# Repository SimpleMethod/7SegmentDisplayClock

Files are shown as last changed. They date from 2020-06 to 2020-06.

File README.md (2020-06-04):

# 🕰️ 7 Segment display clock - simple segment clock based on the STM32 MCU using GPS time as a reference source.

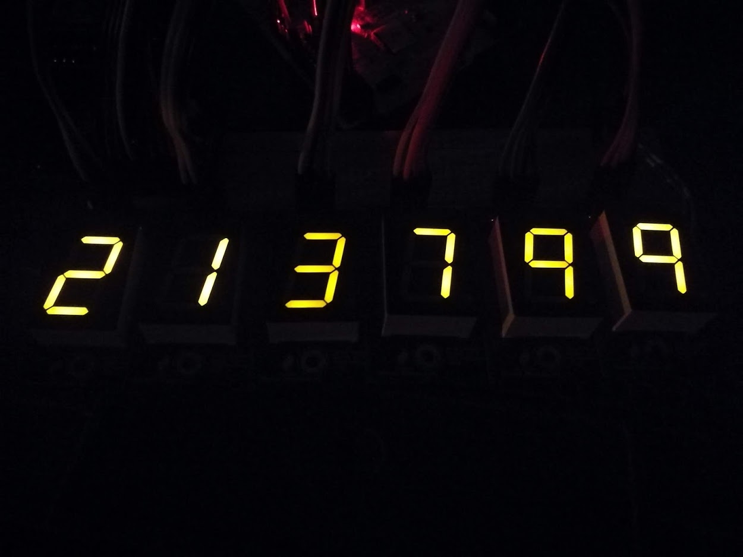
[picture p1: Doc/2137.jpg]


# 🧗‍♂️Main milestones

1. Retrieving date and time from GPS and saving it to RTC.
2. Creating a PCB to display numbers using a 7 segment display.

# 🚀 Features
 1. Retrieving date and time from GPS.
2.  Information users by buzzer signals. 
3.  Setting alarms.
4.  Display date and time on 7 segment display.

# 🗺️ Technologies used in project 
 - Based on microcontroller STM32
- Used CD4511BE as BCD code decoder.
- Used GPS Ublox NEO-M8 as GPS signal receiver.
- Used DS3212 as RTC clock.
-  Development necessary libraries based on technical documentation,

# 🧪 Visualization PCB shield
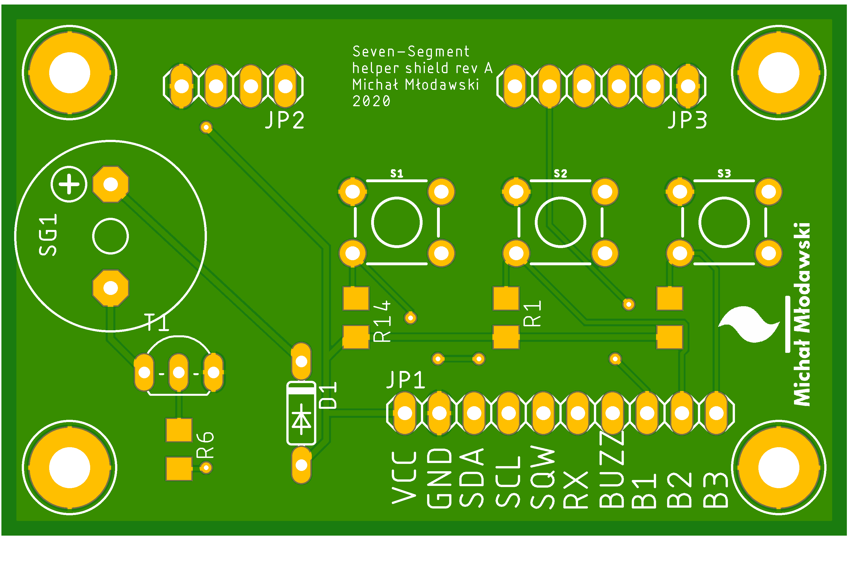
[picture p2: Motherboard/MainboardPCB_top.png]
MainShield


# 🧪 Visualization PCB display top side
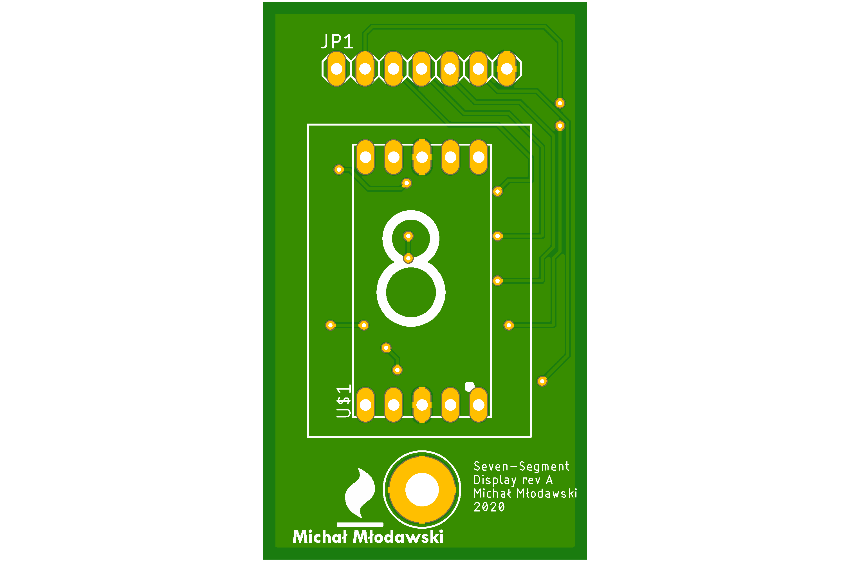
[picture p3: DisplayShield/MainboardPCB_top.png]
dispaly top


# 🧪 Visualization PCB display bottom side

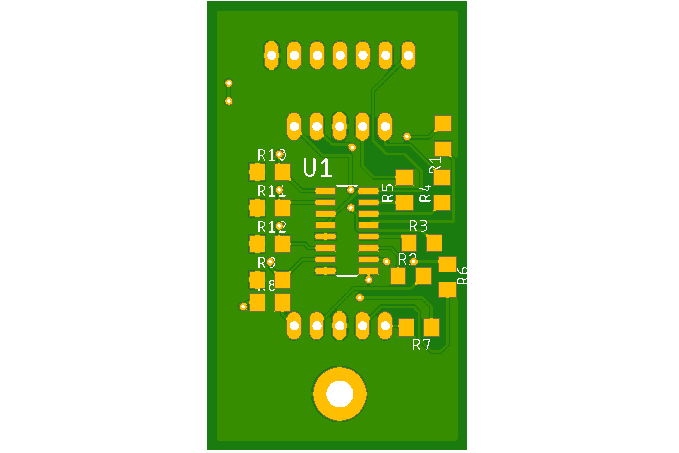
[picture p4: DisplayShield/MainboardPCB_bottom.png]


# ⚡ Circuit diagrams

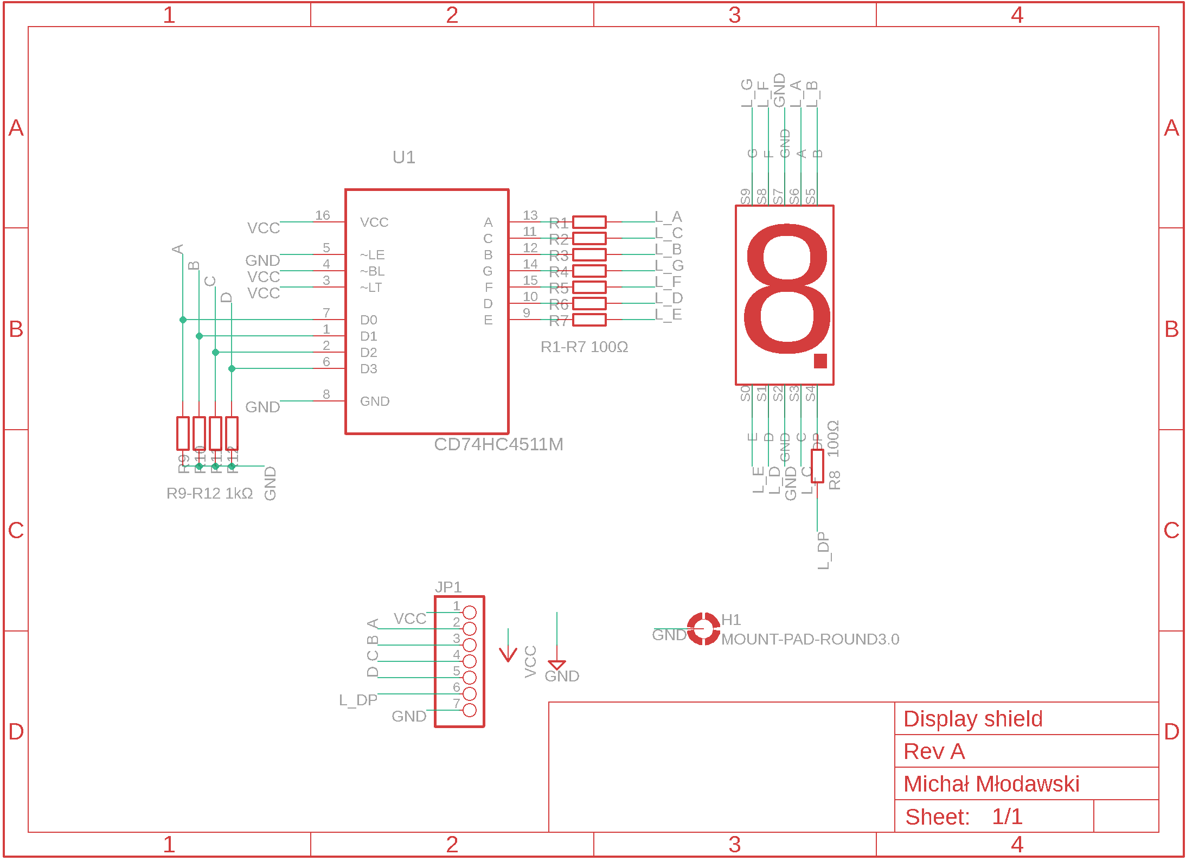
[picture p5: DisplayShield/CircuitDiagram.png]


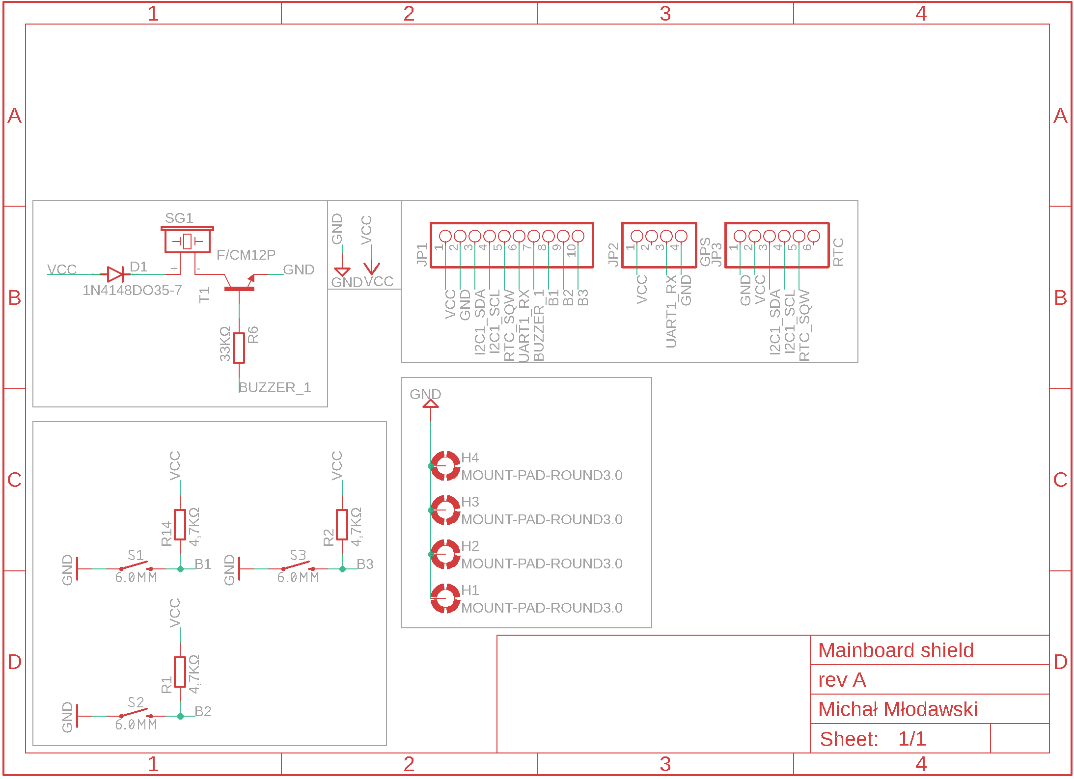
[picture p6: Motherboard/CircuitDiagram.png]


## 🎥  Video of the presentation:

[https://youtu.be/eESlLnk6x-c](https://youtu.be/eESlLnk6x-c)

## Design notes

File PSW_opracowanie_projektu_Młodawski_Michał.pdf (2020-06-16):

For educational purposes only

# Politechnika Świętokrzyska w Kielcach

# Wydział Elektroniki, Automatyki i Informatyki

## Projekt: Programowanie Systemów Wbudowanych

### Grupa:

### 1ID21A

## Temat:

## Zegar z wyświetlaczem siedmiosegmentowym

### Skład grupy:

### Michał Młodawski

### Rok studiów:

4

## Zegar z wyświetlaczem siedmiosegmentowym – Pobieranie czasu z sytemu GPS

## Opracowanie projektu

## Czerwiec 2020

Wersja dokumentu 16062020-001PL

# 1. Opis projektu

Projekt miał na celu stworzenie zegara opartego na wyświetlaczu siedmiosegmentowym umożliwiającym pobieranie daty i godziny przy użyciu sygnału GPS (ang. Global Positioning System), następnie zapisaniu daty i godziny do zegara czasu rzeczywistego RTC DS3231 i wyświetlenie ich następnie na wyświetlaczach siedmiosegmentowych.

# 2. Wykorzystane technologie

Jako główny mikrokontroler został wykorzystany mikrokontroler STM32F411RETx do pobierania czasu z systemu pozycjonowania GPS został użyty układ ublox neo-6m, natomiast do przechowywania czasu układ DS3231. Jako kontroler wyświetlaczy został wykorzystany układ scalony CD4511BE.

# 3. Opis wyświetlacza siedmiosegmentowy

Wyświetlacz siedmiosegmentowy jest sterowany CD4511BE poprzez podanie kodu BCD na wejścia sterujące.

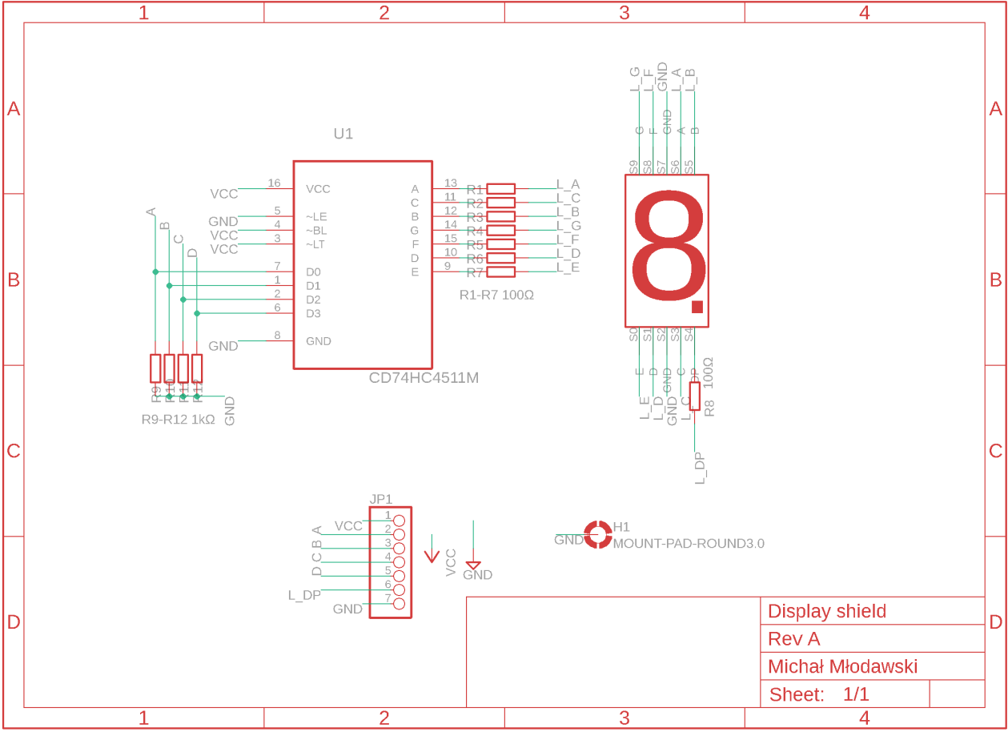
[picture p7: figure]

Rysunek 1 Schemat elektryczny przedstawiający sposób podłączenia układu scalonego do wyświetlacza. Źródło: Opracowanie własne

Rezystory R1-R7 służą do ograniczenia prądu anodowego, rezystory R9-R12 są to rezystory podciągające linie sterujące. Układ sterujący CD4511BE pracuje w logice od 3.3V do 18V, więc nie było potrzebny tworzyć żadnych kluczy tranzystorowych lub dzielników napięć.

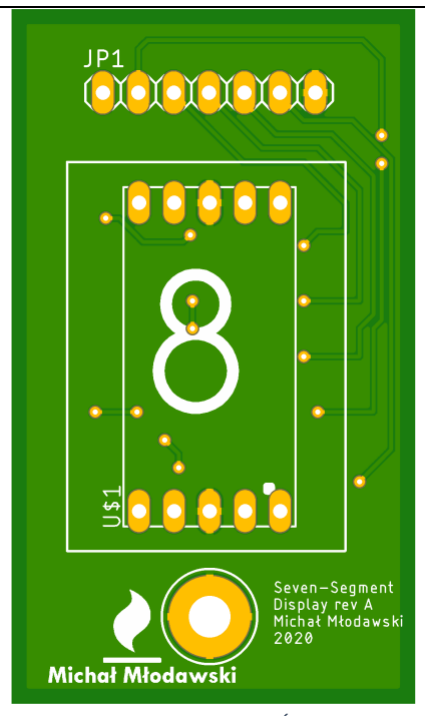
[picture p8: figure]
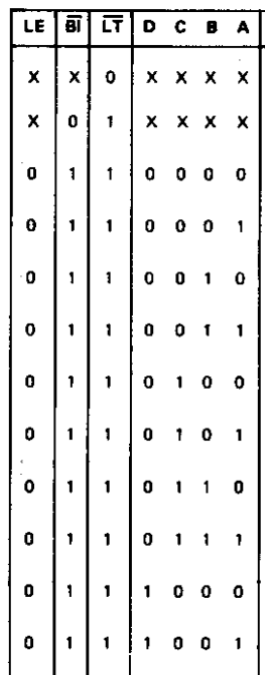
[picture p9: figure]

Tabela 1 Tablica prawdy dla CD4511BE Źródło: https://www.ti.com/lit/ds/symlink/cd4511b.pdf?ts=1592323109630

Wizualizacja płyty PCB kontrolera wyświetlacza siedmiosegmentowego:

Rysunek 2 Strona wierzchnia PCB Źródło: Opracowanie własne

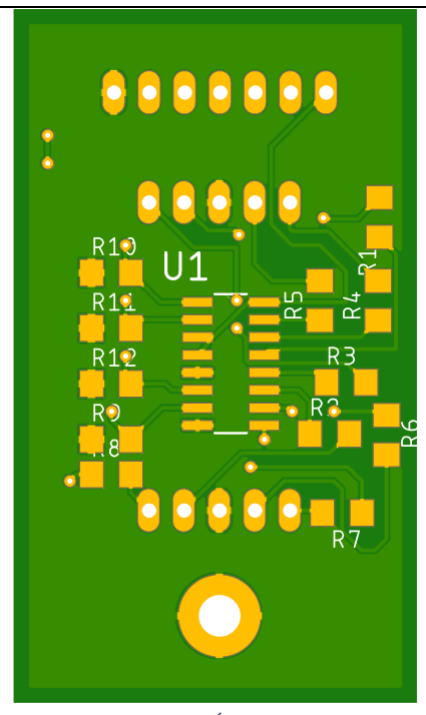
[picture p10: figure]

Rysunek 3 Strona tylna PCB Źródło: Opracowanie własne

Tablica prawdy dla kontrolera CD4511BE:

Tablica prawdy jest to zbiór możliwych kombinacji stanów w celu osiągniecia określonych wyników. Natomiast kod BCD jest to sposób zapisu liczby polegający na zakodowaniu kolejnych cyfr dziesiętnych tej liczby w systemie dwójkowym, przy użyciu tylko czterech młodszych bitów.

# 4. Opis kontrolera

Kontroler składa się z trzech przycisków w konfiguracji pull-up z podciągniętymi rezystorami do zasilania 3.3V. Zostały także dodane wyprowadzenia dla zegara czasu rzeczywistego, odbiornika GPS oraz buzzera kontrolowanego poprzez tranzystor NPN pracującego w formie klucza tranzystorowego, który z racji wykorzystania tranzystora bipolarnego ogranicza prąd pobierany przez buzzer. Dodatkowo dodano diodę 1N4148 w celu zapobiegnięcia zakłóceniom na linii zasilania. Niestety z racji zastosowania zwykłej diody powoduje ona spadek napięcia na buzzerze, ale nie wpływa to negatywnie na jego głośność.

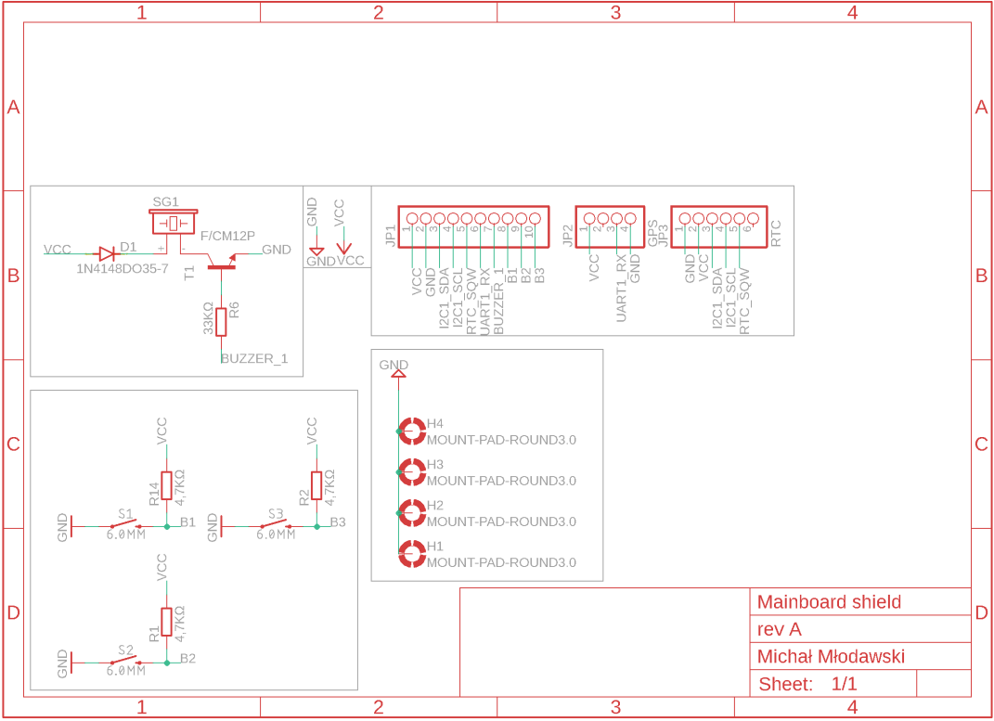
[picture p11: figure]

Rysunek 4 Schemat elektryczny kontrolera Źródło: Opracowanie własne

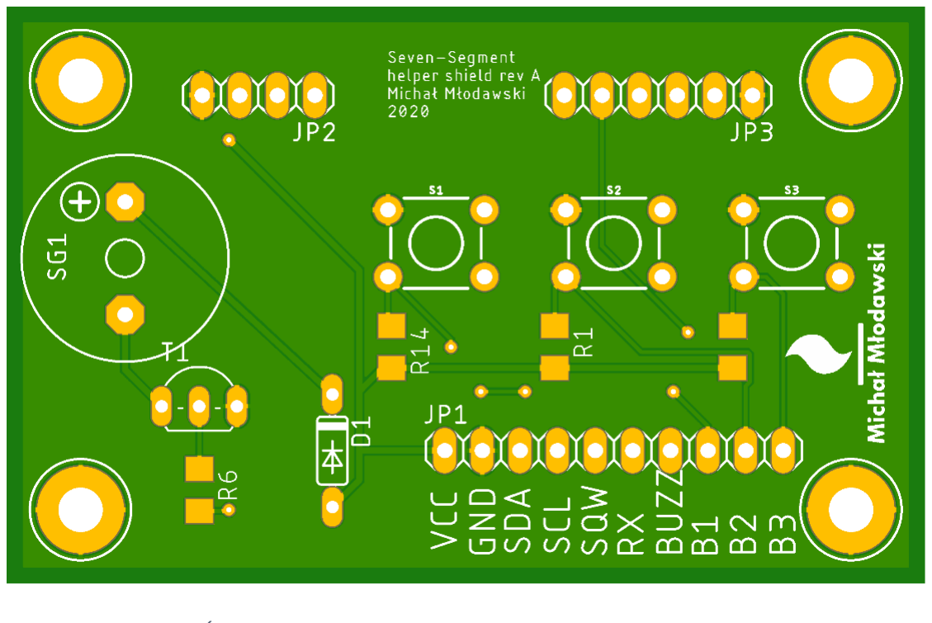
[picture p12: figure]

Rysunek 5 Strona wierzchnia PCB Źródło: Opracowanie własne

# 5. Omówienie warstwy sprzętowej

W tym rozdziale zostaną omówione wszystkie elementy sprzętowe systemu składającego się na gotowe rozwiązanie spełniające założenia projektowe.

## 5.1 Opis zastosowanych standardów komunikacyjnych

Sercem projektu został mikrokontroler z rodziny STM32, a dokładniej STM32F411RETx. Został on wyposażony w rdzeń ARM Cortex-M4 o maksymalnym taktowaniu wynoszącym 100MHz. Do pobierania danych z układu GPS został wykorzystany standard transmisji UART z prędkością wynoszącą 9600 bitów na sekundę z długością słowa wynoszącą 8 bitów. Aby zapewnić szybszą obsługę danych co jest kluczowe do pobierania czasu wykorzystano przerwania NVIC, które informują kontroler o określonym zdarzeniu. W celu pobierania i zapisywania danych do układu RTC DS3231 wykorzystano standard I2C z prędkością 400000Hz, podobnie jak w przypadku komunikacji UART tutaj także wykorzystano przerwania systemowe. Trzy przyciski zostały dodatkowo podciągnięte wewnętrznymi rezystorami Pull-up i przerwanie zostanie aktywowane gdy zbocze sygnału będzie opadające. Poniżej przedstawiam diagram wyprowadzeń dla mikrokontrolera. Jak można zauważyć nie został wykorzystany mechanizm multipleksowania. Co skutkuje zajęciem prawie wszystkich dostępnych wyjść.

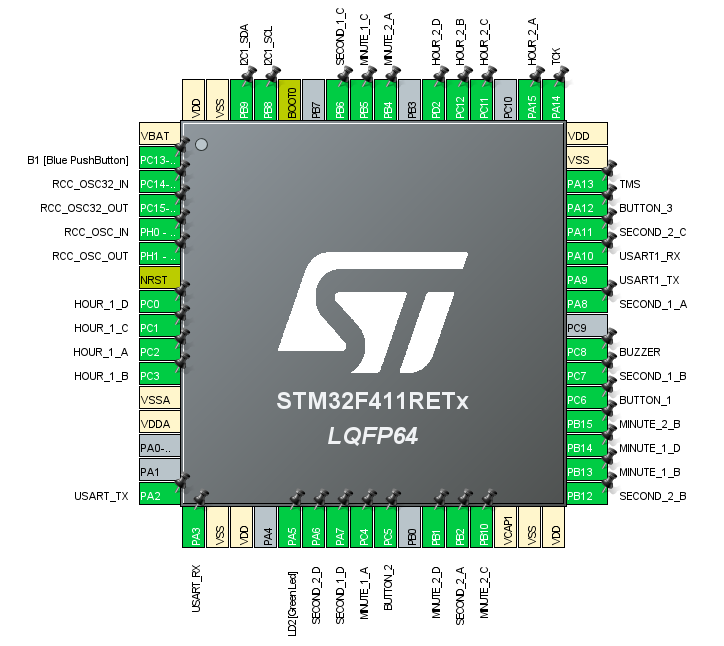
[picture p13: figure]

Rysunek 6 Wyprowadzenia układu Źródło: Opracowanie własne

## 5.2 Taktowanie zegara STM32

Niestety mimo, że według specyfikacji mikrokontroler może pracować z częstotliwością do 100MHz taka częstotliwość pracy nie była możliwa do uzyskania z racji korzystania z dwóch różnych standardów komunikacji, które korzystają z dwóch różnych przebiegów czasowych. W tym celu zdecydowałem się użyć wewnętrznego rezonatora o taktowaniu 16MHz, a następnie poprzez pętlę PLCLK/HSI wygenerować zegar o częstotliwości 84MHz, który umożliwił poprawne działanie wszystkich układów.

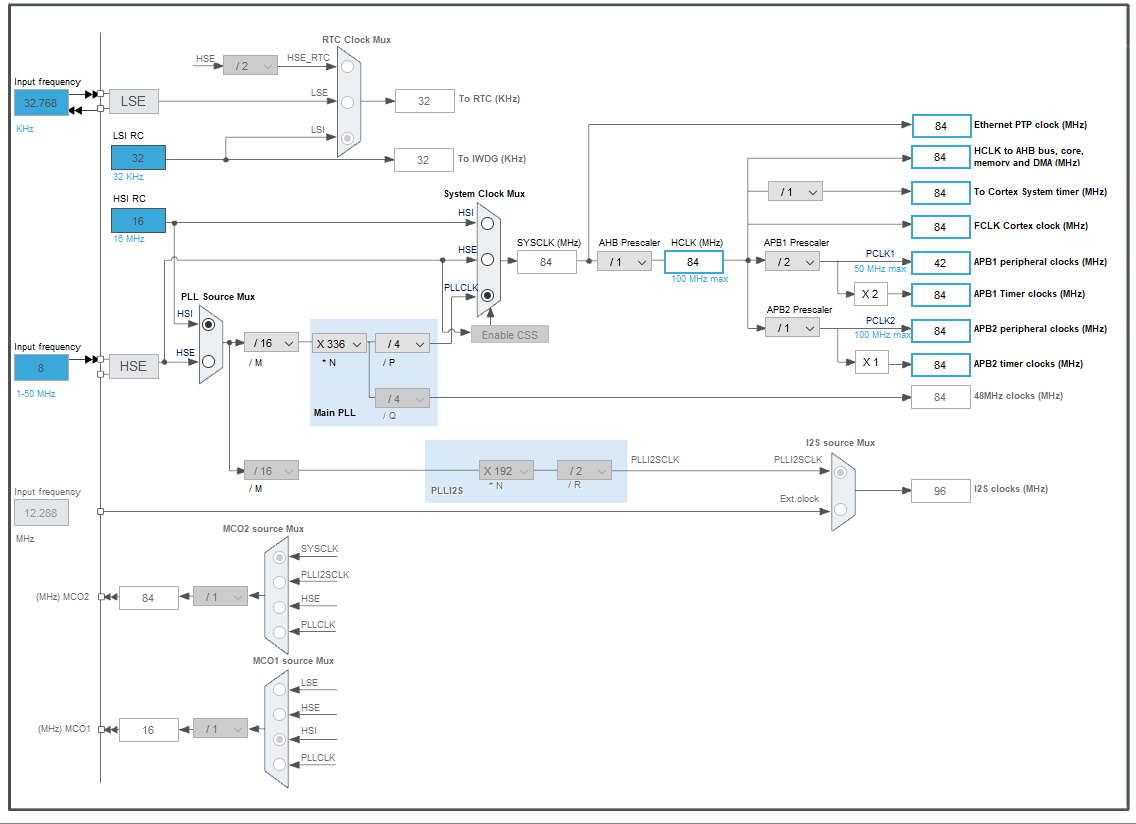
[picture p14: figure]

Rysunek 7 Taktowanie procesora w programie STM32CubeIDE Źródło: Opracowanie własne

## 5.3 Opis układu neo-6m i technologii GPS

Do pobierania sygnału GPS (ang. Global Positioning System) został wykorzystany moduł neo-6m firmy ublox, który wspiera protokół UART i pracuje w logice 3.3V. Czas do nawiązania sygnału i synchronizowania się wynosi tylko 26 sekund od „zimnego startu”, czyli stanu gdy moduł niesynchronizowań się od dłuższego czasu, a czas pobrania danych w przypadku „ciepłego startu” wynosi poniżej 1 sekundy.

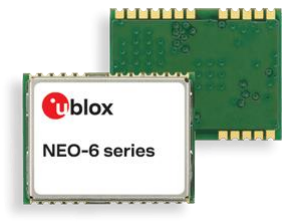
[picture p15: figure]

Rysunek 8 Wygląd modułu GPS Źródło: https://www.u-blox.com/en/product/neo-6-series

Aby lepiej zrozumieć zasadę działania należałoby omówić jak działa system globalnej lokalizacji, jednakże celem projektu było pobranie czasu i daty, a nie lokalizacji, dlatego przytoczę tylko krótki fragment definicji:

Każdy satelita transmituje unikalny sygnał i parametry orbitalne, które pozwalają urządzeniom GPS dekodować i obliczać dokładną lokalizację satelity. [...] Dzięki pomiarom odległości z kilku kolejnych satelitów odbiornik może ustalić pozycję użytkownika i zanalizować ją.

Źródło: https://bearpoint.pl/czym-jest-gps/ Dostęp: 16.06.2020 r.

Znacznie ciekawszym zagadnieniem z punktu widzenia projektu jest pobranie godziny i daty z użyciem standardu komunikacyjnego NMEA. System GPS w zależności od generacji potrafi odebrać od 11 do 58 różnych komunikatów. Dzięki standardu NMEA mamy dosyć dużą odporność na błędy, pojedyncza wiadomość zawsze będzie zawierać 82 znaki (puste informacje zostają zastąpione spacjami), komunikat zaczyna się od znaku $, a kończy \n\r. Dodatkowo każda wiadomość zawiera sumę kontrolną. W projekcie został wykorzystany komunikat $GPRMC (Recommended minimum specific GPS/Transit data) został on zaprezentowany poniżej:

$GPRMC,123519,A,4807.038,N,01131.000,E,022.4,084.4,230394,003.1,W*6A

Opis poszczególnych parametrów:

- 123519 – Aktualność danych - 12:35:19 UTC,
- A – status (A – aktywny; V – nieaktywny),
- 4807.038,N – szerokość geograficzna (latitude) 48 deg 07.038' N,
- 01131.000,E – długość geograficzna (longitude) - 11 deg 31.000' E,
- 022.4 – prędkość obiektu (liczona w węzłach),
- 084.4 – kąt śledzenia/poruszania się obiektu (w stopniach) przydatny w celu określenia kierunku poruszania się obiektu, jeżeli urządzenie GPS nie jest wyposażone w kompas,
- 230394 – data (23 marca 1994),
- 003.1,W – odchylenie magnetyczne ziemi,
- *6A – suma kontrolna.

Źródło: http://www.systemy.ztt.edu.pl/pobierz/instrukcje/nmea.pdf Dostęp: 16.06.2020

Układ ublox neo-6m odbiera 19 głównych wiadomości dodatkowo posiada system ostrzegający o próbie zakłócenia sygnału.

## 5.4 Układ czasu rzeczywistego DS3231

W celu zarządzanie czasem rzeczywistym został wykorzystany układ DS3231 firmy Maxim Integrated pracujący w logice 3.3V zasilany napięciem 3.3V z podtrzymaniem bateryjnym CR2032, które przełącza się automatycznie w momencie utraty głównego zasilania (co pozwala na dłuższe „życie” baterii). Sam układ sterowany jest za pomocą standardu komunikacyjnego I2C pracującym z częstotliwością do 400 kHz. Komunikacja polega na zapisie i odczycie poszczególnych rejestrów znajdujących się pod określonymi adresami. Z racji na zjawisko dryfu rezonatorów kwarcowych w tym układzie został wykorzystany wewnętrzny rezonator 32.768kHz z kompensacjom temperaturową (TCXO)

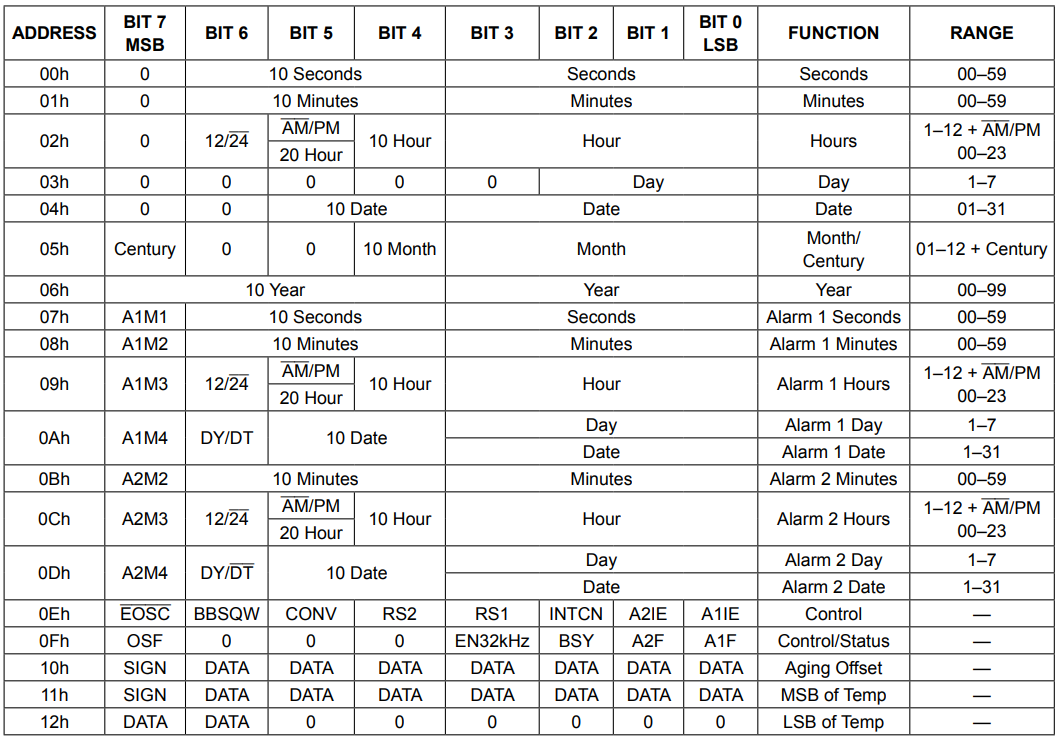
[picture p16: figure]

Tabela 2 Tablica adresów i rejestrów zegara RTC Źródło: https://datasheets.maximintegrated.com/en/ds/DS3231.pdf

# 6. Omówienie warstwy programowej

Dzięki rdzeniowy ARM CorteX możliwe jest programowanie w języku Asembler, C, C++. Projekt został napisany w języku C dzięki czemu wsad zajmuje mniej miejsca, wykorzystuje dwie biblioteki DS3231.h oraz gps_neo6.h, które zostały napisane w celu obsługi zegara RTC i GPS.

## 6.1 Biblioteka DS3231.h

Jest to biblioteka odpowiedzialna za komunikację z zegarem RTC. Głównie wykorzystuje metodę „HAL_I2C_Mem_Read” do odczytu danych i „HAL_I2C_Mem_Write” do zapisu danych. Dodatkowo zostały zainicjalizowane dwie struktury, która jedna przechowuje odczytane dane, a druga zapisane. Obie struktury zawierają wszystkie dane niezbędne do poprawnego funkcjonowania układu, czyli sekundę, minutę, godzinę, dzień, miesiąc, rok. Należy pamiętać, że dane są zapisane według strefy czasowej UTC.

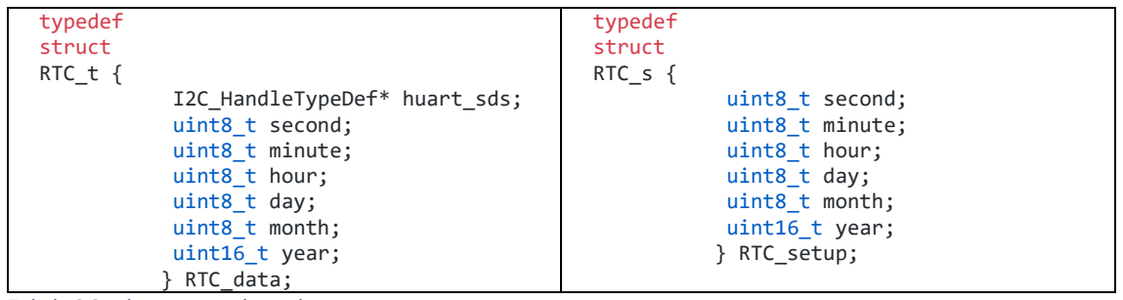
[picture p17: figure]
typedef; struct; RTC_t {; RTC_s {; I2C_HandleTypeDef* huart_sds; uint8_t second; uint8_t minute; uint8_t hour; uint8_t day; uint8_t month; uint16_t year; } RTC_data;; uint8_t second; uint8_t minute; uint8_t hour; uint8_t day; uint8_t month; uint16_t year; } RTC_setup;

Tabela 3 Struktury gromadzące dane.

## 6.2 Biblioteka gps_neo6.h

Biblioteka odpowiedzialna za odczyt danych z GPS. Dzięki znajomości maksymalnego rozmiaru wiadomości $GPRMC można było łatwo i szybko z pośród odebranych wiadomości znaleźć naszą i zdekodować używając metody stroke.

## 6.3 Główny program

Główny program zajmuje się zarządzaniem odczytami, a wyświetlaniem danych na wyświetlaczu siedmiosegmentowym. Zostały zdefiniowane niezbędne zmienne w celu obsługi przycisków, alarmu, a także trybu konfiguracyjnego. Kod BCD został na sztywno zaimplementowany do każdego z wyświetlaczy (numerowanych co 2, np. Hour_1, Hour_2 itp.). Aby móc zapewnić wyświetlenie liczby składającej się z dwóch cyfr został wykorzystany mechanizm modulo i dzielenia, przykładowy kod wyświetlający minuty został zaprezentowany poniżej:

void
DisplayMinute(int
digit) {
int part1 = digit / 10;
int part2 = digit % 10;
SprintMinute_1(part1);
SprintMinute_2(part2);
}

Za odczytywanie stanów przycisków i menu wyboru opcji konfiguracji została zrealizowana w przerwaniu HAL_GPIO_EXTI_Callback. Działa na zasadzie sprawdzenia stanu poszczególnych pinów, jeżeli pin odpowiedzialny za przycisk jeden zostanie wciśnięty zmienia się stan logiczny przerwanie systemowe to odnotowuje. Menu oferuje takie opcje jak:

- Zmiana strefy czasowej (do przodu lub do tyłu) – Aktywacja przyciskiem 1, zmiany strefy czasowej przyciskami 2 i 3. Wyjście z menu przyciskiem 1.
- Zapisanie alarmu (godzina i minuta) ) – Aktywacja przyciskiem 2, zmiana godziny przyciskiem 1, zmiana minuty przyciskiem 2. Zapisanie alarmu ponownym przyciśnięciem przycisku 2.
- Wyświetlanie aktualnej daty – Aktywacja przyciskiem 3, wyjście z menu przyciskiem 3.

Program sygnalizuje pracę sygnalizacją dźwiękową, po tym sygnale zaczyna się działanie programu. Program pobiera datę z RTC i w tle oczekuje na nawiązanie połączenia przez system GPS, jednocześnie nie blokując działania programu. W momencie aktualizacji GPS magistrala UART wysyła przerwanie do procesora i dane zostają zapisane w jednym cyklu do układu RTC, synchronizacja z GPS sygnalizowana jest dźwiękiem. Co 100 milisekund następuje pobranie daty z RTC i odświeżenie wyświetlacza siedmiosegmentowego, co nie wypływa na opóźnienie zegara RTC ponieważ on pracuje samodzielnie.

GPS w momencie aktualizacji już nie aktualizuje ponieważ to by powodowało wyłącznie zajmowanie czasu procesora. Samo memu konfiguracji dzięki zastosowaniu przerwań systemowych także nie powoduje dryfu czasu tak samo jak aktywacja alarmu.Niestety projekt z racji ograniczonych przycisków wspiera wyłącznie jeden powtarzalny alarm (Powtarza się co określonej godzinie).

W projekcie przed możliwymi zakleszczeniami zastosowano prymitywne semafory np. aby buzzer nie wydawał dźwięków przez całą minutę po skończeniu metody zmienia stan zmiennej kontrolnej, podobnie jest z całym menu konfiguracyjnym i pobieraniem czasu z GPS.

# 7. Podsumowanie projektu

Projekt okazał się niezwykle interesujący, łącząc elementy sprzętowe i programowe można było osiągnąć kompaktowe rozwiązane dostosowane do potrzeb projektu. Dzięki zaprojektowaniu płytek drukowanych znacząco zmniejszono rozmiar prototypu oraz uniknięto przypadkowego połączenia złych elementów co mogłoby narazić na szkody finansowe i/lub zdrowotne. Chciałbym także podziękować dr hab. inż. Grzegorza Radomskiego za cenne wskazówki udzielone podczas prac nad projektem. Na koniec prezentuję gotowe rozwiązanie w formie zdjęć.

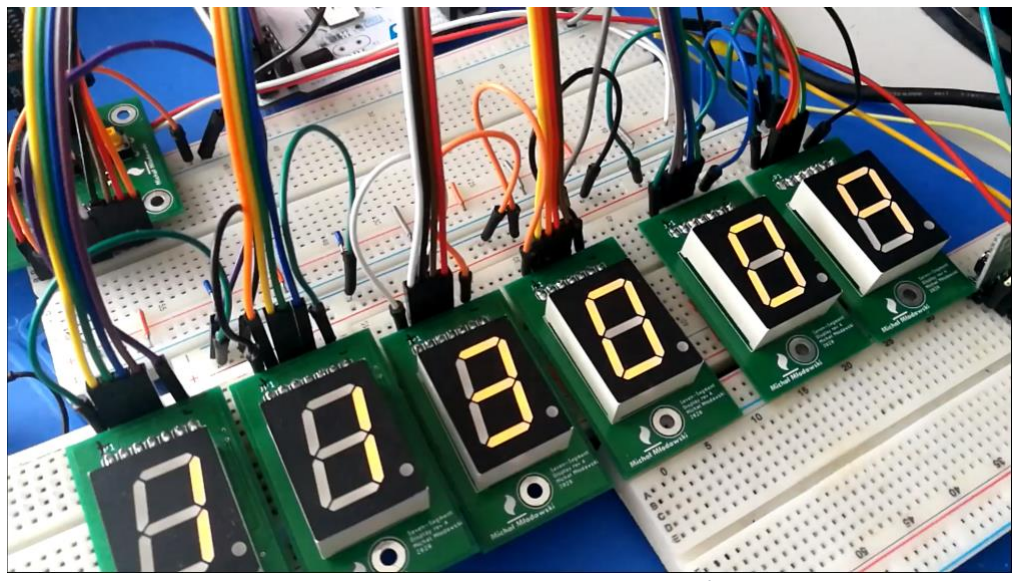
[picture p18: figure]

Rysunek 9 Zegar siedmiosegmentowy zdjęcie prezentujące wyświetlacz i godzinę Źródło: opracowanie własne

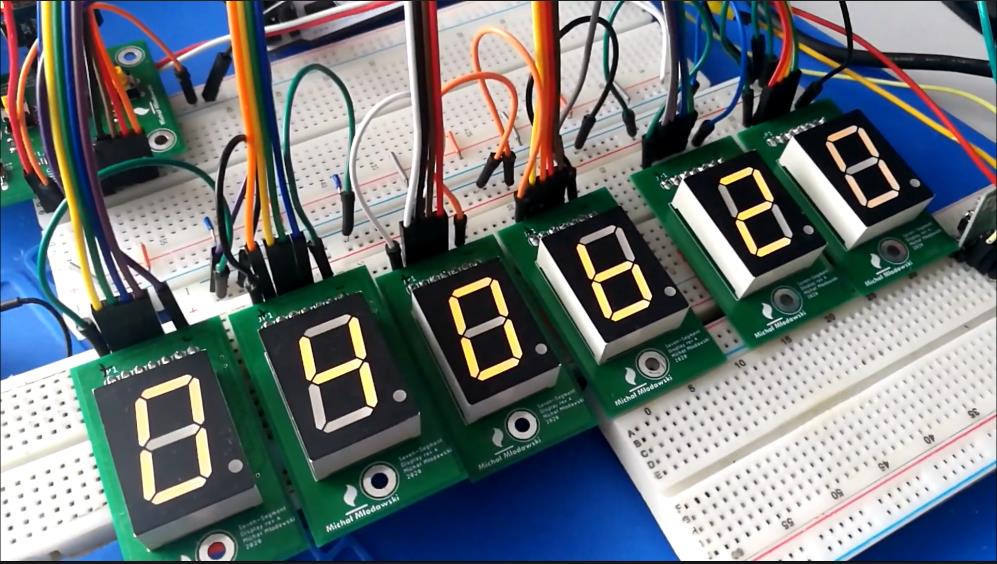
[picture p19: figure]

Rysunek 10 Zegar siedmiosegmentowy zdjęcie prezentujące wyświetlacz i datę Źródło: opracowanie własne

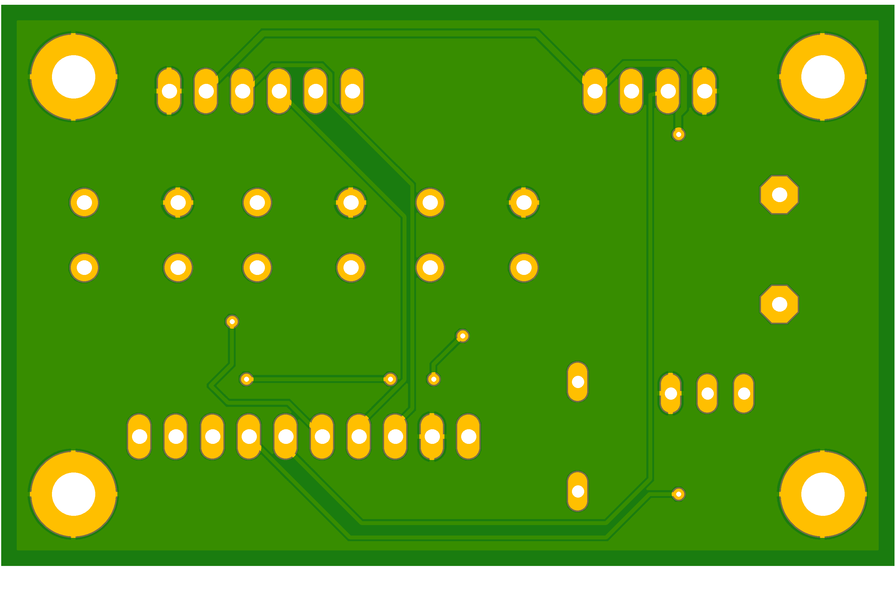
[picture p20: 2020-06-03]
Motherboard/MainboardPCB_bottom.png

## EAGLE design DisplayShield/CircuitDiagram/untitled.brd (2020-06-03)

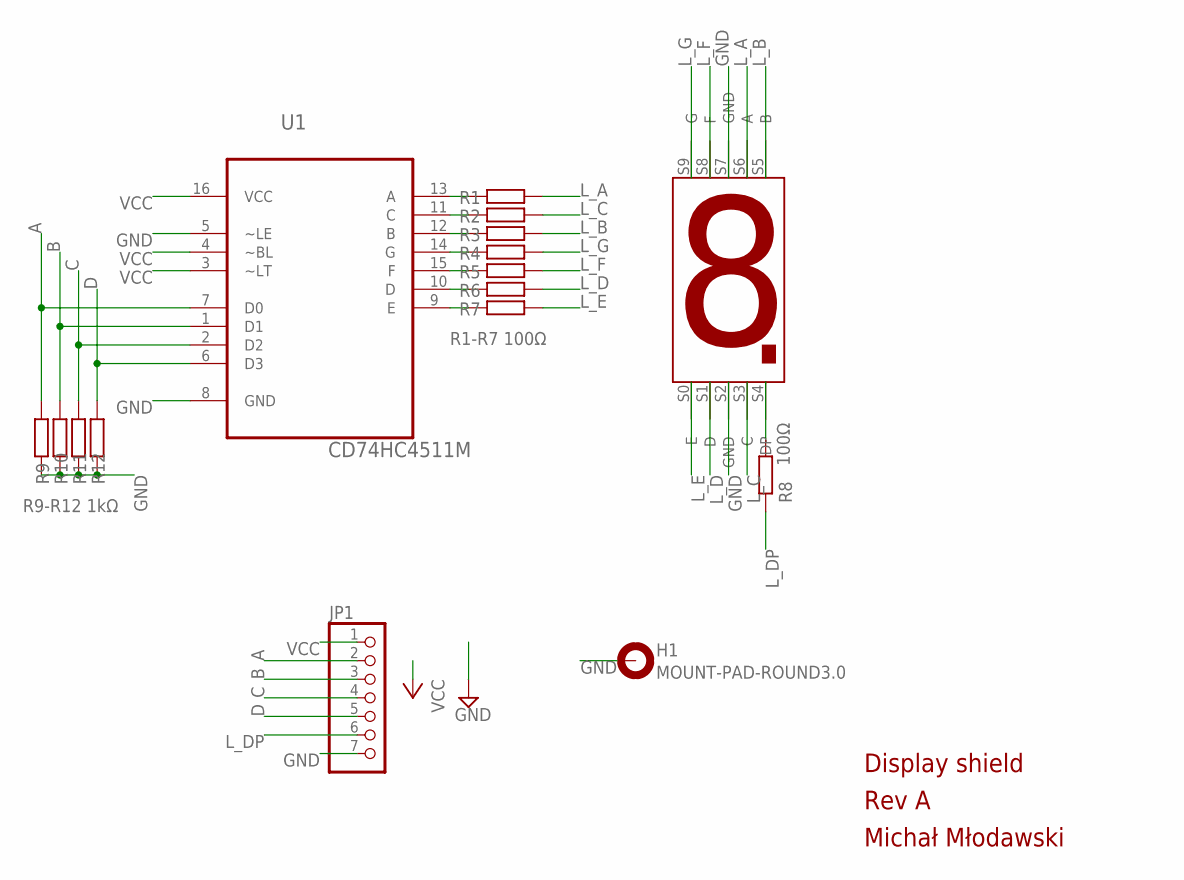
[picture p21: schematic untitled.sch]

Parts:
H1: MOUNT-PAD-ROUND3.0; 3,0-PAD
JP1: PINHD-1X7; 1X07
R1, R2, R3, R4, R5, R6, R7, R9, R10, R11, R12: R-EU_R1206; R1206
R8: 100Ω; R1206
U1: CD74HC4511M; SOIC127P600X175-16N
U$1: 7-SEGMENT-DISPLAY; 7-SEGMENTDISPLAY

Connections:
A: JP1.2, R9.2, U1.7 (D0)
B: JP1.3, R10.2, U1.1 (D1)
C: JP1.4, R11.2, U1.2 (D2)
D: JP1.5, R12.2, U1.6 (D3)
GND: H1.B3,0, JP1.7, R9.1, R10.1, R11.1, R12.1, U1.5 (~LE), U1.8 (GND), U$1.S2 (GND), U$1.S7 (GND)
L_A: R1.2, U$1.S6 (A)
L_B: R3.2, U$1.S5 (B)
L_C: R2.2, U$1.S3 (C)
L_D: R6.2, U$1.S1 (D)
L_DP: JP1.6, R8.1
L_E: R7.2, U$1.S0 (E)
L_F: R5.2, U$1.S8 (F)
L_G: R4.2, U$1.S9 (G)
unnamed: R1.1, U1.13 (A)
unnamed: R2.1, U1.11 (C)
unnamed: R3.1, U1.12 (B)
unnamed: R4.1, U1.14 (G)
unnamed: R5.1, U1.15 (F)
unnamed: R6.1, U1.10 (D)
unnamed: R7.1, U1.9 (E)
unnamed: R8.2, U$1.S4 (DP)
VCC: JP1.1, U1.3 (~LT), U1.4 (~BL), U1.16 (VCC)

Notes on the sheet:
R1-R7 100Ω
R9-R12 1kΩ
Michał Młodawski
Rev A
Display shield

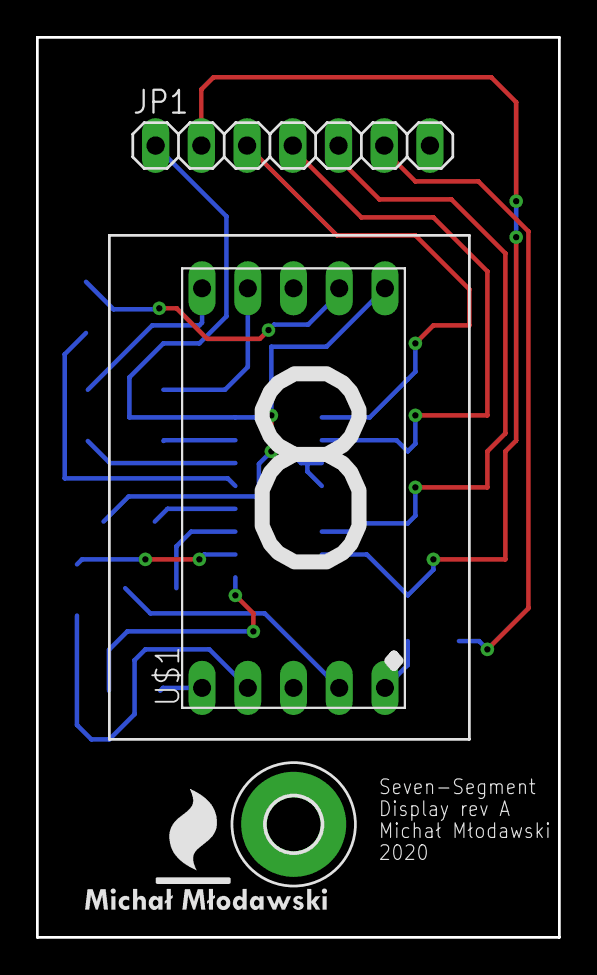
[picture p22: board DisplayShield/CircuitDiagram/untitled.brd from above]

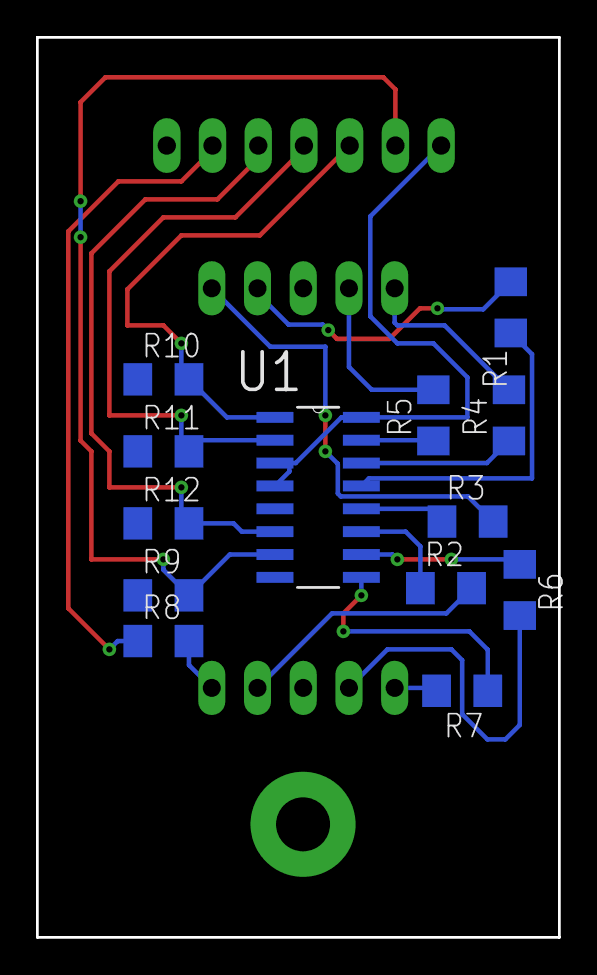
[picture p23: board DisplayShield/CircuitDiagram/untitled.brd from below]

Board: 2 copper layers, 29.0 x 50.0 mm, 16 parts (13 on the bottom side), 22 nets.

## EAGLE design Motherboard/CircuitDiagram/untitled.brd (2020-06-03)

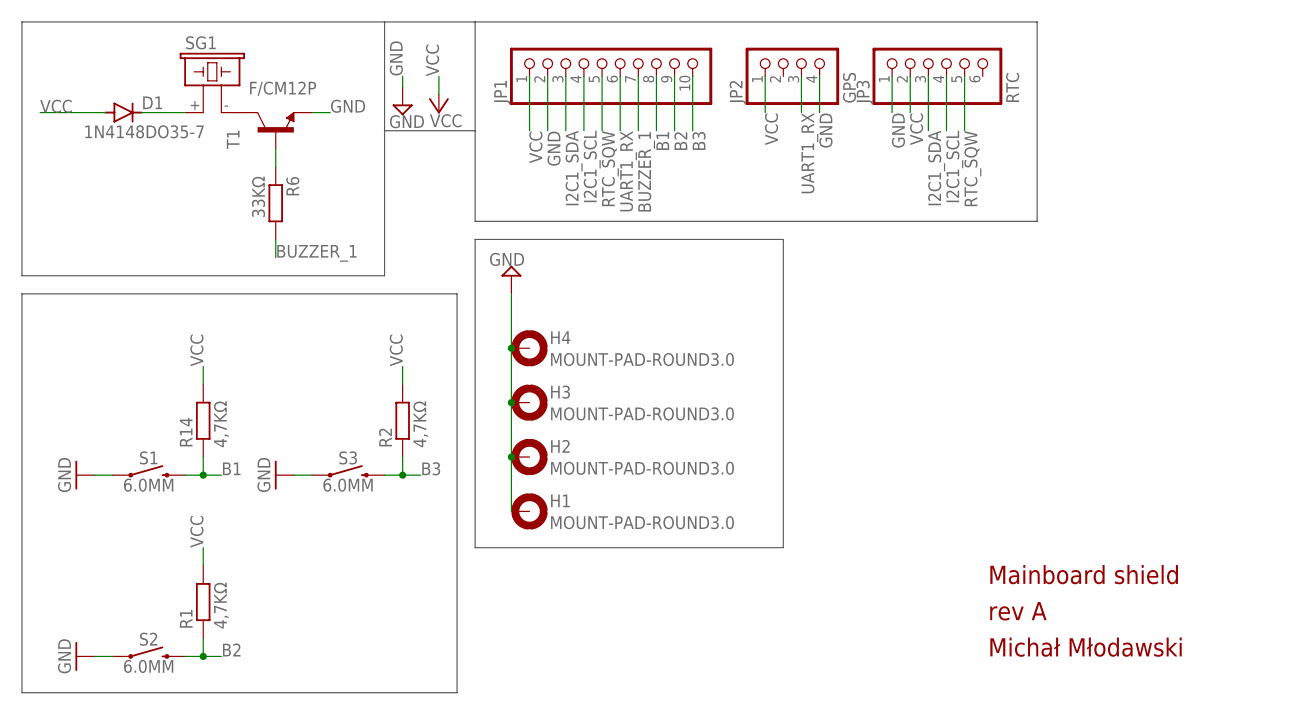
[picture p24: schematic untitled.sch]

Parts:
D1: 1N4148DO35-7; DO35-7
H1, H2, H3, H4: MOUNT-PAD-ROUND3.0; 3,0-PAD
JP1: PINHD-1X10; 1X10
JP2: GPS; 1X04
JP3: RTC; 1X06
R1, R2, R14: 4,7KΩ; R1206
R6: 33KΩ; R1206
S1, S2, S3: 6.0MM; TACTILE_SWITCH_PTH_6.0MM
SG1: F/CM12P
T1: BC548-NPN-TO92-CBE; TO92-CBE

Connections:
B1: JP1.8, R14.1, S1.3 (2)
B2: JP1.9, R1.1, S2.3 (2)
B3: JP1.10, R2.1, S3.3 (2)
BUZZER_1: JP1.7, R6.2
GND: H1.B3,0, H2.B3,0, H3.B3,0, H4.B3,0, JP1.2, JP2.4, JP3.1, S1.1, S2.1, S3.1, T1.E
I2C1_SCL: JP1.4, JP3.4
I2C1_SDA: JP1.3, JP3.3
unnamed: D1.C, SG1.+ (1)
unnamed: SG1.- (2), T1.C
unnamed: R6.1, T1.B
RTC_SQW: JP1.5, JP3.5
UART1_RX: JP1.6, JP2.3
VCC: D1.A, JP1.1, JP2.1, JP3.2, R1.2, R2.2, R14.2

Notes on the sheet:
Michał Młodawski
rev A
Mainboard shield

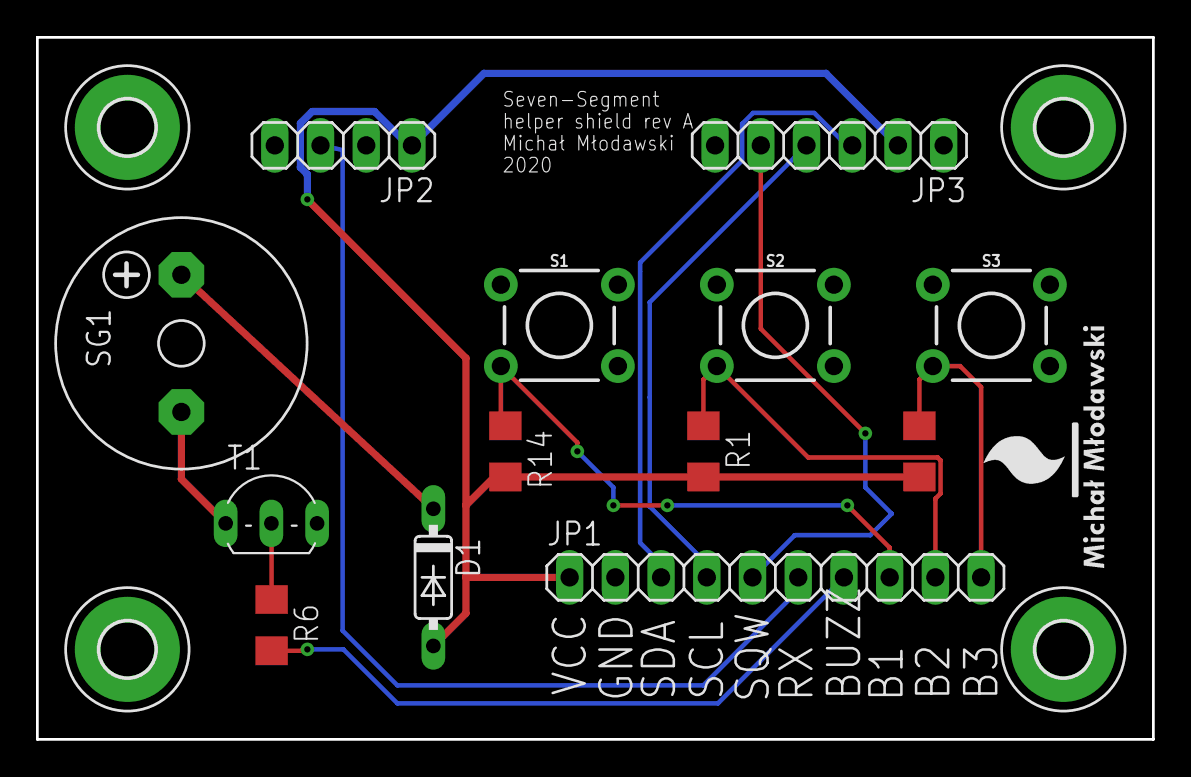
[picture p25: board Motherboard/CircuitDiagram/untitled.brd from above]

Board: 2 copper layers, 62.0 x 39.0 mm, 17 parts (0 on the bottom side), 13 nets.

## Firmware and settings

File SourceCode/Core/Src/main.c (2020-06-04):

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

/* Includes ------------------------------------------------------------------*/
#include "main.h"

/* USER CODE BEGIN Includes */
#include <DS3231.h>
#include <gps_neo6.h>
#include <stdio.h>
#include <stdarg.h>
#include <stdlib.h>
#include <string.h>
/* USER CODE END Includes */

I2C_HandleTypeDef hi2c1;

UART_HandleTypeDef huart1;
UART_HandleTypeDef huart2;

/* USER CODE BEGIN PV */

RTC_data rtc;	// Date and Time variable
RTC_setup rtc_setup;

uint8_t muttexButton1 = 0;
uint8_t muttexButton2 = 0;
uint8_t muttexButton3 = 0;
uint8_t configMode = 0;

uint8_t alarmHour = 0;
uint8_t alarmMinute = 0;
uint8_t alarmDeactivate = 0;

/** Config mode 1 */

signed short timeOffset = 0;

/* USER CODE END PV */

void SystemClock_Config(void);
static void MX_GPIO_Init(void);
static void MX_USART2_UART_Init(void);
static void MX_I2C1_Init(void);
static void MX_USART1_UART_Init(void);
/* USER CODE BEGIN PFP */
/*
 void vprint(const char *fmt, va_list argp) {
 char string[200];
 if (0 < vsprintf(string, fmt, argp)) // build string
 {
 HAL_UART_Transmit(&huart2, (uint8_t*) string, strlen(string), 0xffffff); // send message via UART
 }
 }

 void my_printf(const char *fmt, ...) // custom printf() function
 {
 va_list argp;
 va_start(argp, fmt);
 vprint(fmt, argp);
 va_end(argp);
 }
 */
/* USER CODE END PFP */

/* USER CODE BEGIN 0 */

void SprintHour_1(int digit) {
	switch (digit) {
	case 0:
		HAL_GPIO_WritePin(HOUR_1_D_GPIO_Port, HOUR_1_D_Pin, GPIO_PIN_RESET);
		HAL_GPIO_WritePin(HOUR_1_C_GPIO_Port, HOUR_1_C_Pin, GPIO_PIN_RESET);
		HAL_GPIO_WritePin(HOUR_1_B_GPIO_Port, HOUR_1_B_Pin, GPIO_PIN_RESET);
		HAL_GPIO_WritePin(HOUR_1_A_GPIO_Port, HOUR_1_A_Pin, GPIO_PIN_RESET);
		break;
	case 1:
		HAL_GPIO_WritePin(HOUR_1_D_GPIO_Port, HOUR_1_D_Pin, GPIO_PIN_RESET);
		HAL_GPIO_WritePin(HOUR_1_C_GPIO_Port, HOUR_1_C_Pin, GPIO_PIN_RESET);
		HAL_GPIO_WritePin(HOUR_1_B_GPIO_Port, HOUR_1_B_Pin, GPIO_PIN_RESET);
		HAL_GPIO_WritePin(HOUR_1_A_GPIO_Port, HOUR_1_A_Pin, GPIO_PIN_SET);
		break;
	case 2:
		HAL_GPIO_WritePin(HOUR_1_D_GPIO_Port, HOUR_1_D_Pin, GPIO_PIN_RESET);
		HAL_GPIO_WritePin(HOUR_1_C_GPIO_Port, HOUR_1_C_Pin, GPIO_PIN_RESET);
		HAL_GPIO_WritePin(HOUR_1_B_GPIO_Port, HOUR_1_B_Pin, GPIO_PIN_SET);
		HAL_GPIO_WritePin(HOUR_1_A_GPIO_Port, HOUR_1_A_Pin, GPIO_PIN_RESET);
		break;
	case 3:
		HAL_GPIO_WritePin(HOUR_1_D_GPIO_Port, HOUR_1_D_Pin, GPIO_PIN_RESET);
		HAL_GPIO_WritePin(HOUR_1_C_GPIO_Port, HOUR_1_C_Pin, GPIO_PIN_RESET);
		HAL_GPIO_WritePin(HOUR_1_B_GPIO_Port, HOUR_1_B_Pin, GPIO_PIN_SET);
		HAL_GPIO_WritePin(HOUR_1_A_GPIO_Port, HOUR_1_A_Pin, GPIO_PIN_SET);
		break;
	case 4:
		HAL_GPIO_WritePin(HOUR_1_D_GPIO_Port, HOUR_1_D_Pin, GPIO_PIN_RESET);
		HAL_GPIO_WritePin(HOUR_1_C_GPIO_Port, HOUR_1_C_Pin, GPIO_PIN_SET);
		HAL_GPIO_WritePin(HOUR_1_B_GPIO_Port, HOUR_1_B_Pin, GPIO_PIN_RESET);
		HAL_GPIO_WritePin(HOUR_1_A_GPIO_Port, HOUR_1_A_Pin, GPIO_PIN_RESET);
		break;
	case 5:
		HAL_GPIO_WritePin(HOUR_1_D_GPIO_Port, HOUR_1_D_Pin, GPIO_PIN_RESET);
		HAL_GPIO_WritePin(HOUR_1_C_GPIO_Port, HOUR_1_C_Pin, GPIO_PIN_SET);
		HAL_GPIO_WritePin(HOUR_1_B_GPIO_Port, HOUR_1_B_Pin, GPIO_PIN_RESET);
		HAL_GPIO_WritePin(HOUR_1_A_GPIO_Port, HOUR_1_A_Pin, GPIO_PIN_SET);
		break;
	case 6:
		HAL_GPIO_WritePin(HOUR_1_D_GPIO_Port, HOUR_1_D_Pin, GPIO_PIN_RESET);
		HAL_GPIO_WritePin(HOUR_1_C_GPIO_Port, HOUR_1_C_Pin, GPIO_PIN_SET);
		HAL_GPIO_WritePin(HOUR_1_B_GPIO_Port, HOUR_1_B_Pin, GPIO_PIN_SET);
		HAL_GPIO_WritePin(HOUR_1_A_GPIO_Port, HOUR_1_A_Pin, GPIO_PIN_RESET);
		break;
	case 7:
		HAL_GPIO_WritePin(HOUR_1_D_GPIO_Port, HOUR_1_D_Pin, GPIO_PIN_RESET);
		HAL_GPIO_WritePin(HOUR_1_C_GPIO_Port, HOUR_1_C_Pin, GPIO_PIN_SET);
		HAL_GPIO_WritePin(HOUR_1_B_GPIO_Port, HOUR_1_B_Pin, GPIO_PIN_SET);
		HAL_GPIO_WritePin(HOUR_1_A_GPIO_Port, HOUR_1_A_Pin, GPIO_PIN_SET);
		break;
	case 8:
		HAL_GPIO_WritePin(HOUR_1_D_GPIO_Port, HOUR_1_D_Pin, GPIO_PIN_SET);
		HAL_GPIO_WritePin(HOUR_1_C_GPIO_Port, HOUR_1_C_Pin, GPIO_PIN_RESET);
		HAL_GPIO_WritePin(HOUR_1_B_GPIO_Port, HOUR_1_B_Pin, GPIO_PIN_RESET);
		HAL_GPIO_WritePin(HOUR_1_A_GPIO_Port, HOUR_1_A_Pin, GPIO_PIN_RESET);
		break;
	case 9:
		HAL_GPIO_WritePin(HOUR_1_D_GPIO_Port, HOUR_1_D_Pin, GPIO_PIN_SET);
		HAL_GPIO_WritePin(HOUR_1_C_GPIO_Port, HOUR_1_C_Pin, GPIO_PIN_RESET);
		HAL_GPIO_WritePin(HOUR_1_B_GPIO_Port, HOUR_1_B_Pin, GPIO_PIN_RESET);
		HAL_GPIO_WritePin(HOUR_1_A_GPIO_Port, HOUR_1_A_Pin, GPIO_PIN_SET);
		break;
	default:
		break;
	}
}

void SprintHour_2(int digit) {
	switch (digit) {
	case 0:
		HAL_GPIO_WritePin(HOUR_2_D_GPIO_Port, HOUR_2_D_Pin, GPIO_PIN_RESET);
		HAL_GPIO_WritePin(HOUR_2_C_GPIO_Port, HOUR_2_C_Pin, GPIO_PIN_RESET);
		HAL_GPIO_WritePin(HOUR_2_B_GPIO_Port, HOUR_2_B_Pin, GPIO_PIN_RESET);
		HAL_GPIO_WritePin(HOUR_2_A_GPIO_Port, HOUR_2_A_Pin, GPIO_PIN_RESET);
		break;
	case 1:
		HAL_GPIO_WritePin(HOUR_2_D_GPIO_Port, HOUR_2_D_Pin, GPIO_PIN_RESET);
		HAL_GPIO_WritePin(HOUR_2_C_GPIO_Port, HOUR_2_C_Pin, GPIO_PIN_RESET);
		HAL_GPIO_WritePin(HOUR_2_B_GPIO_Port, HOUR_2_B_Pin, GPIO_PIN_RESET);
		HAL_GPIO_WritePin(HOUR_2_A_GPIO_Port, HOUR_2_A_Pin, GPIO_PIN_SET);
		break;
	case 2:
		HAL_GPIO_WritePin(HOUR_2_D_GPIO_Port, HOUR_2_D_Pin, GPIO_PIN_RESET);
		HAL_GPIO_WritePin(HOUR_2_C_GPIO_Port, HOUR_2_C_Pin, GPIO_PIN_RESET);
		HAL_GPIO_WritePin(HOUR_2_B_GPIO_Port, HOUR_2_B_Pin, GPIO_PIN_SET);
		HAL_GPIO_WritePin(HOUR_2_A_GPIO_Port, HOUR_2_A_Pin, GPIO_PIN_RESET);
		break;
	case 3:
		HAL_GPIO_WritePin(HOUR_2_D_GPIO_Port, HOUR_2_D_Pin, GPIO_PIN_RESET);
		HAL_GPIO_WritePin(HOUR_2_C_GPIO_Port, HOUR_2_C_Pin, GPIO_PIN_RESET);
		HAL_GPIO_WritePin(HOUR_2_B_GPIO_Port, HOUR_2_B_Pin, GPIO_PIN_SET);
		HAL_GPIO_WritePin(HOUR_2_A_GPIO_Port, HOUR_2_A_Pin, GPIO_PIN_SET);
		break;
	case 4:
		HAL_GPIO_WritePin(HOUR_2_D_GPIO_Port, HOUR_2_D_Pin, GPIO_PIN_RESET);
		HAL_GPIO_WritePin(HOUR_2_C_GPIO_Port, HOUR_2_C_Pin, GPIO_PIN_SET);
		HAL_GPIO_WritePin(HOUR_2_B_GPIO_Port, HOUR_2_B_Pin, GPIO_PIN_RESET);
		HAL_GPIO_WritePin(HOUR_2_A_GPIO_Port, HOUR_2_A_Pin, GPIO_PIN_RESET);
		break;
	case 5:
		HAL_GPIO_WritePin(HOUR_2_D_GPIO_Port, HOUR_2_D_Pin, GPIO_PIN_RESET);
		HAL_GPIO_WritePin(HOUR_2_C_GPIO_Port, HOUR_2_C_Pin, GPIO_PIN_SET);
		HAL_GPIO_WritePin(HOUR_2_B_GPIO_Port, HOUR_2_B_Pin, GPIO_PIN_RESET);
		HAL_GPIO_WritePin(HOUR_2_A_GPIO_Port, HOUR_2_A_Pin, GPIO_PIN_SET);
		break;
	case 6:
		HAL_GPIO_WritePin(HOUR_2_D_GPIO_Port, HOUR_2_D_Pin, GPIO_PIN_RESET);
		HAL_GPIO_WritePin(HOUR_2_C_GPIO_Port, HOUR_2_C_Pin, GPIO_PIN_SET);
		HAL_GPIO_WritePin(HOUR_2_B_GPIO_Port, HOUR_2_B_Pin, GPIO_PIN_SET);
		HAL_GPIO_WritePin(HOUR_2_A_GPIO_Port, HOUR_2_A_Pin, GPIO_PIN_RESET);
		break;
	case 7:
		HAL_GPIO_WritePin(HOUR_2_D_GPIO_Port, HOUR_2_D_Pin, GPIO_PIN_RESET);
		HAL_GPIO_WritePin(HOUR_2_C_GPIO_Port, HOUR_2_C_Pin, GPIO_PIN_SET);
		HAL_GPIO_WritePin(HOUR_2_B_GPIO_Port, HOUR_2_B_Pin, GPIO_PIN_SET);
		HAL_GPIO_WritePin(HOUR_2_A_GPIO_Port, HOUR_2_A_Pin, GPIO_PIN_SET);
		break;
	case 8:
		HAL_GPIO_WritePin(HOUR_2_D_GPIO_Port, HOUR_2_D_Pin, GPIO_PIN_SET);
		HAL_GPIO_WritePin(HOUR_2_C_GPIO_Port, HOUR_2_C_Pin, GPIO_PIN_RESET);
		HAL_GPIO_WritePin(HOUR_2_B_GPIO_Port, HOUR_2_B_Pin, GPIO_PIN_RESET);
		HAL_GPIO_WritePin(HOUR_2_A_GPIO_Port, HOUR_2_A_Pin, GPIO_PIN_RESET);
		break;
	case 9:
		HAL_GPIO_WritePin(HOUR_2_D_GPIO_Port, HOUR_2_D_Pin, GPIO_PIN_SET);
		HAL_GPIO_WritePin(HOUR_2_C_GPIO_Port, HOUR_2_C_Pin, GPIO_PIN_RESET);
		HAL_GPIO_WritePin(HOUR_2_B_GPIO_Port, HOUR_2_B_Pin, GPIO_PIN_RESET);
		HAL_GPIO_WritePin(HOUR_2_A_GPIO_Port, HOUR_2_A_Pin, GPIO_PIN_SET);
		break;
	default:
		break;
	}
}

void SprintMinute_1(int digit) {
	switch (digit) {
	case 0:
		HAL_GPIO_WritePin(MINUTE_1_D_GPIO_Port, MINUTE_1_D_Pin, GPIO_PIN_RESET);
		HAL_GPIO_WritePin(MINUTE_1_C_GPIO_Port, MINUTE_1_C_Pin, GPIO_PIN_RESET);
		HAL_GPIO_WritePin(MINUTE_1_B_GPIO_Port, MINUTE_1_B_Pin, GPIO_PIN_RESET);
		HAL_GPIO_WritePin(MINUTE_1_A_GPIO_Port, MINUTE_1_A_Pin, GPIO_PIN_RESET);
		break;
	case 1:
		HAL_GPIO_WritePin(MINUTE_1_D_GPIO_Port, MINUTE_1_D_Pin, GPIO_PIN_RESET);
		HAL_GPIO_WritePin(MINUTE_1_C_GPIO_Port, MINUTE_1_C_Pin, GPIO_PIN_RESET);
		HAL_GPIO_WritePin(MINUTE_1_B_GPIO_Port, MINUTE_1_B_Pin, GPIO_PIN_RESET);
		HAL_GPIO_WritePin(MINUTE_1_A_GPIO_Port, MINUTE_1_A_Pin, GPIO_PIN_SET);
		break;
	case 2:
		HAL_GPIO_WritePin(MINUTE_1_D_GPIO_Port, MINUTE_1_D_Pin, GPIO_PIN_RESET);
		HAL_GPIO_WritePin(MINUTE_1_C_GPIO_Port, MINUTE_1_C_Pin, GPIO_PIN_RESET);
		HAL_GPIO_WritePin(MINUTE_1_B_GPIO_Port, MINUTE_1_B_Pin, GPIO_PIN_SET);
		HAL_GPIO_WritePin(MINUTE_1_A_GPIO_Port, MINUTE_1_A_Pin, GPIO_PIN_RESET);
		break;
	case 3:
		HAL_GPIO_WritePin(MINUTE_1_D_GPIO_Port, MINUTE_1_D_Pin, GPIO_PIN_RESET);
		HAL_GPIO_WritePin(MINUTE_1_C_GPIO_Port, MINUTE_1_C_Pin, GPIO_PIN_RESET);
		HAL_GPIO_WritePin(MINUTE_1_B_GPIO_Port, MINUTE_1_B_Pin, GPIO_PIN_SET);
		HAL_GPIO_WritePin(MINUTE_1_A_GPIO_Port, MINUTE_1_A_Pin, GPIO_PIN_SET);
		break;
	case 4:
		HAL_GPIO_WritePin(MINUTE_1_D_GPIO_Port, MINUTE_1_D_Pin, GPIO_PIN_RESET);
		HAL_GPIO_WritePin(MINUTE_1_C_GPIO_Port, MINUTE_1_C_Pin, GPIO_PIN_SET);
		HAL_GPIO_WritePin(MINUTE_1_B_GPIO_Port, MINUTE_1_B_Pin, GPIO_PIN_RESET);
		HAL_GPIO_WritePin(MINUTE_1_A_GPIO_Port, MINUTE_1_A_Pin, GPIO_PIN_RESET);
		break;
	case 5:
		HAL_GPIO_WritePin(MINUTE_1_D_GPIO_Port, MINUTE_1_D_Pin, GPIO_PIN_RESET);
		HAL_GPIO_WritePin(MINUTE_1_C_GPIO_Port, MINUTE_1_C_Pin, GPIO_PIN_SET);
		HAL_GPIO_WritePin(MINUTE_1_B_GPIO_Port, MINUTE_1_B_Pin, GPIO_PIN_RESET);
		HAL_GPIO_WritePin(MINUTE_1_A_GPIO_Port, MINUTE_1_A_Pin, GPIO_PIN_SET);
		break;
	case 6:
		HAL_GPIO_WritePin(MINUTE_1_D_GPIO_Port, MINUTE_1_D_Pin, GPIO_PIN_RESET);
		HAL_GPIO_WritePin(MINUTE_1_C_GPIO_Port, MINUTE_1_C_Pin, GPIO_PIN_SET);
		HAL_GPIO_WritePin(MINUTE_1_B_GPIO_Port, MINUTE_1_B_Pin, GPIO_PIN_SET);
		HAL_GPIO_WritePin(MINUTE_1_A_GPIO_Port, MINUTE_1_A_Pin, GPIO_PIN_RESET);
		break;
	case 7:
		HAL_GPIO_WritePin(MINUTE_1_D_GPIO_Port, MINUTE_1_D_Pin, GPIO_PIN_RESET);
		HAL_GPIO_WritePin(MINUTE_1_C_GPIO_Port, MINUTE_1_C_Pin, GPIO_PIN_SET);
		HAL_GPIO_WritePin(MINUTE_1_B_GPIO_Port, MINUTE_1_B_Pin, GPIO_PIN_SET);
		HAL_GPIO_WritePin(MINUTE_1_A_GPIO_Port, MINUTE_1_A_Pin, GPIO_PIN_SET);
		break;
	case 8:
		HAL_GPIO_WritePin(MINUTE_1_D_GPIO_Port, MINUTE_1_D_Pin, GPIO_PIN_SET);
		HAL_GPIO_WritePin(MINUTE_1_C_GPIO_Port, MINUTE_1_C_Pin, GPIO_PIN_RESET);
		HAL_GPIO_WritePin(MINUTE_1_B_GPIO_Port, MINUTE_1_B_Pin, GPIO_PIN_RESET);
		HAL_GPIO_WritePin(MINUTE_1_A_GPIO_Port, MINUTE_1_A_Pin, GPIO_PIN_RESET);
		break;
	case 9:
		HAL_GPIO_WritePin(MINUTE_1_D_GPIO_Port, MINUTE_1_D_Pin, GPIO_PIN_SET);
		HAL_GPIO_WritePin(MINUTE_1_C_GPIO_Port, MINUTE_1_C_Pin, GPIO_PIN_RESET);
		HAL_GPIO_WritePin(MINUTE_1_B_GPIO_Port, MINUTE_1_B_Pin, GPIO_PIN_RESET);
		HAL_GPIO_WritePin(MINUTE_1_A_GPIO_Port, MINUTE_1_A_Pin, GPIO_PIN_SET);
		break;
	default:
		break;
	}
}

void SprintMinute_2(int digit) {
	switch (digit) {
	case 0:
		HAL_GPIO_WritePin(MINUTE_2_D_GPIO_Port, MINUTE_2_D_Pin, GPIO_PIN_RESET);
		HAL_GPIO_WritePin(MINUTE_2_C_GPIO_Port, MINUTE_2_C_Pin, GPIO_PIN_RESET);
		HAL_GPIO_WritePin(MINUTE_2_B_GPIO_Port, MINUTE_2_B_Pin, GPIO_PIN_RESET);
		HAL_GPIO_WritePin(MINUTE_2_A_GPIO_Port, MINUTE_2_A_Pin, GPIO_PIN_RESET);
		break;
	case 1:
		HAL_GPIO_WritePin(MINUTE_2_D_GPIO_Port, MINUTE_2_D_Pin, GPIO_PIN_RESET);
		HAL_GPIO_WritePin(MINUTE_2_C_GPIO_Port, MINUTE_2_C_Pin, GPIO_PIN_RESET);
		HAL_GPIO_WritePin(MINUTE_2_B_GPIO_Port, MINUTE_2_B_Pin, GPIO_PIN_RESET);
		HAL_GPIO_WritePin(MINUTE_2_A_GPIO_Port, MINUTE_2_A_Pin, GPIO_PIN_SET);
		break;
	case 2:
		HAL_GPIO_WritePin(MINUTE_2_D_GPIO_Port, MINUTE_2_D_Pin, GPIO_PIN_RESET);
		HAL_GPIO_WritePin(MINUTE_2_C_GPIO_Port, MINUTE_2_C_Pin, GPIO_PIN_RESET);
		HAL_GPIO_WritePin(MINUTE_2_B_GPIO_Port, MINUTE_2_B_Pin, GPIO_PIN_SET);
		HAL_GPIO_WritePin(MINUTE_2_A_GPIO_Port, MINUTE_2_A_Pin, GPIO_PIN_RESET);
		break;
	case 3:
		HAL_GPIO_WritePin(MINUTE_2_D_GPIO_Port, MINUTE_2_D_Pin, GPIO_PIN_RESET);
		HAL_GPIO_WritePin(MINUTE_2_C_GPIO_Port, MINUTE_2_C_Pin, GPIO_PIN_RESET);
		HAL_GPIO_WritePin(MINUTE_2_B_GPIO_Port, MINUTE_2_B_Pin, GPIO_PIN_SET);
		HAL_GPIO_WritePin(MINUTE_2_A_GPIO_Port, MINUTE_2_A_Pin, GPIO_PIN_SET);
		break;
	case 4:
		HAL_GPIO_WritePin(MINUTE_2_D_GPIO_Port, MINUTE_2_D_Pin, GPIO_PIN_RESET);
		HAL_GPIO_WritePin(MINUTE_2_C_GPIO_Port, MINUTE_2_C_Pin, GPIO_PIN_SET);
		HAL_GPIO_WritePin(MINUTE_2_B_GPIO_Port, MINUTE_2_B_Pin, GPIO_PIN_RESET);
		HAL_GPIO_WritePin(MINUTE_2_A_GPIO_Port, MINUTE_2_A_Pin, GPIO_PIN_RESET);
		break;
	case 5:
		HAL_GPIO_WritePin(MINUTE_2_D_GPIO_Port, MINUTE_2_D_Pin, GPIO_PIN_RESET);
		HAL_GPIO_WritePin(MINUTE_2_C_GPIO_Port, MINUTE_2_C_Pin, GPIO_PIN_SET);
		HAL_GPIO_WritePin(MINUTE_2_B_GPIO_Port, MINUTE_2_B_Pin, GPIO_PIN_RESET);
		HAL_GPIO_WritePin(MINUTE_2_A_GPIO_Port, MINUTE_2_A_Pin, GPIO_PIN_SET);
		break;
	case 6:
		HAL_GPIO_WritePin(MINUTE_2_D_GPIO_Port, MINUTE_2_D_Pin, GPIO_PIN_RESET);
		HAL_GPIO_WritePin(MINUTE_2_C_GPIO_Port, MINUTE_2_C_Pin, GPIO_PIN_SET);
		HAL_GPIO_WritePin(MINUTE_2_B_GPIO_Port, MINUTE_2_B_Pin, GPIO_PIN_SET);
		HAL_GPIO_WritePin(MINUTE_2_A_GPIO_Port, MINUTE_2_A_Pin, GPIO_PIN_RESET);
		break;
	case 7:
		HAL_GPIO_WritePin(MINUTE_2_D_GPIO_Port, MINUTE_2_D_Pin, GPIO_PIN_RESET);
		HAL_GPIO_WritePin(MINUTE_2_C_GPIO_Port, MINUTE_2_C_Pin, GPIO_PIN_SET);
		HAL_GPIO_WritePin(MINUTE_2_B_GPIO_Port, MINUTE_2_B_Pin, GPIO_PIN_SET);
		HAL_GPIO_WritePin(MINUTE_2_A_GPIO_Port, MINUTE_2_A_Pin, GPIO_PIN_SET);
		break;
	case 8:
		HAL_GPIO_WritePin(MINUTE_2_D_GPIO_Port, MINUTE_2_D_Pin, GPIO_PIN_SET);
		HAL_GPIO_WritePin(MINUTE_2_C_GPIO_Port, MINUTE_2_C_Pin, GPIO_PIN_RESET);
		HAL_GPIO_WritePin(MINUTE_2_B_GPIO_Port, MINUTE_2_B_Pin, GPIO_PIN_RESET);
		HAL_GPIO_WritePin(MINUTE_2_A_GPIO_Port, MINUTE_2_A_Pin, GPIO_PIN_RESET);
		break;
	case 9:
		HAL_GPIO_WritePin(MINUTE_2_D_GPIO_Port, MINUTE_2_D_Pin, GPIO_PIN_SET);
		HAL_GPIO_WritePin(MINUTE_2_C_GPIO_Port, MINUTE_2_C_Pin, GPIO_PIN_RESET);
		HAL_GPIO_WritePin(MINUTE_2_B_GPIO_Port, MINUTE_2_B_Pin, GPIO_PIN_RESET);
		HAL_GPIO_WritePin(MINUTE_2_A_GPIO_Port, MINUTE_2_A_Pin, GPIO_PIN_SET);
		break;
	default:
		break;
	}
}

void SprintSecond_1(int digit) {
	switch (digit) {
	case 0:
		HAL_GPIO_WritePin(SECOND_1_D_GPIO_Port, SECOND_1_D_Pin, GPIO_PIN_RESET);
		HAL_GPIO_WritePin(SECOND_1_C_GPIO_Port, SECOND_1_C_Pin, GPIO_PIN_RESET);
		HAL_GPIO_WritePin(SECOND_1_B_GPIO_Port, SECOND_1_B_Pin, GPIO_PIN_RESET);
		HAL_GPIO_WritePin(SECOND_1_A_GPIO_Port, SECOND_1_A_Pin, GPIO_PIN_RESET);
		break;
	case 1:
		HAL_GPIO_WritePin(SECOND_1_D_GPIO_Port, SECOND_1_D_Pin, GPIO_PIN_RESET);
		HAL_GPIO_WritePin(SECOND_1_C_GPIO_Port, SECOND_1_C_Pin, GPIO_PIN_RESET);
		HAL_GPIO_WritePin(SECOND_1_B_GPIO_Port, SECOND_1_B_Pin, GPIO_PIN_RESET);
		HAL_GPIO_WritePin(SECOND_1_A_GPIO_Port, SECOND_1_A_Pin, GPIO_PIN_SET);
		break;
	case 2:
		HAL_GPIO_WritePin(SECOND_1_D_GPIO_Port, SECOND_1_D_Pin, GPIO_PIN_RESET);
		HAL_GPIO_WritePin(SECOND_1_C_GPIO_Port, SECOND_1_C_Pin, GPIO_PIN_RESET);
		HAL_GPIO_WritePin(SECOND_1_B_GPIO_Port, SECOND_1_B_Pin, GPIO_PIN_SET);
		HAL_GPIO_WritePin(SECOND_1_A_GPIO_Port, SECOND_1_A_Pin, GPIO_PIN_RESET);
		break;
	case 3:
		HAL_GPIO_WritePin(SECOND_1_D_GPIO_Port, SECOND_1_D_Pin, GPIO_PIN_RESET);
		HAL_GPIO_WritePin(SECOND_1_C_GPIO_Port, SECOND_1_C_Pin, GPIO_PIN_RESET);
		HAL_GPIO_WritePin(SECOND_1_B_GPIO_Port, SECOND_1_B_Pin, GPIO_PIN_SET);
		HAL_GPIO_WritePin(SECOND_1_A_GPIO_Port, SECOND_1_A_Pin, GPIO_PIN_SET);
		break;
	case 4:
		HAL_GPIO_WritePin(SECOND_1_D_GPIO_Port, SECOND_1_D_Pin, GPIO_PIN_RESET);
		HAL_GPIO_WritePin(SECOND_1_C_GPIO_Port, SECOND_1_C_Pin, GPIO_PIN_SET);
		HAL_GPIO_WritePin(SECOND_1_B_GPIO_Port, SECOND_1_B_Pin, GPIO_PIN_RESET);
		HAL_GPIO_WritePin(SECOND_1_A_GPIO_Port, SECOND_1_A_Pin, GPIO_PIN_RESET);
		break;
	case 5:
		HAL_GPIO_WritePin(SECOND_1_D_GPIO_Port, SECOND_1_D_Pin, GPIO_PIN_RESET);
		HAL_GPIO_WritePin(SECOND_1_C_GPIO_Port, SECOND_1_C_Pin, GPIO_PIN_SET);
		HAL_GPIO_WritePin(SECOND_1_B_GPIO_Port, SECOND_1_B_Pin, GPIO_PIN_RESET);
		HAL_GPIO_WritePin(SECOND_1_A_GPIO_Port, SECOND_1_A_Pin, GPIO_PIN_SET);
		break;
	case 6:
		HAL_GPIO_WritePin(SECOND_1_D_GPIO_Port, SECOND_1_D_Pin, GPIO_PIN_RESET);
		HAL_GPIO_WritePin(SECOND_1_C_GPIO_Port, SECOND_1_C_Pin, GPIO_PIN_SET);
		HAL_GPIO_WritePin(SECOND_1_B_GPIO_Port, SECOND_1_B_Pin, GPIO_PIN_SET);
		HAL_GPIO_WritePin(SECOND_1_A_GPIO_Port, SECOND_1_A_Pin, GPIO_PIN_RESET);
		break;
	case 7:
		HAL_GPIO_WritePin(SECOND_1_D_GPIO_Port, SECOND_1_D_Pin, GPIO_PIN_RESET);
		HAL_GPIO_WritePin(SECOND_1_C_GPIO_Port, SECOND_1_C_Pin, GPIO_PIN_SET);
		HAL_GPIO_WritePin(SECOND_1_B_GPIO_Port, SECOND_1_B_Pin, GPIO_PIN_SET);
		HAL_GPIO_WritePin(SECOND_1_A_GPIO_Port, SECOND_1_A_Pin, GPIO_PIN_SET);
		break;
	case 8:
		HAL_GPIO_WritePin(SECOND_1_D_GPIO_Port, SECOND_1_D_Pin, GPIO_PIN_SET);
		HAL_GPIO_WritePin(SECOND_1_C_GPIO_Port, SECOND_1_C_Pin, GPIO_PIN_RESET);
		HAL_GPIO_WritePin(SECOND_1_B_GPIO_Port, SECOND_1_B_Pin, GPIO_PIN_RESET);
		HAL_GPIO_WritePin(SECOND_1_A_GPIO_Port, SECOND_1_A_Pin, GPIO_PIN_RESET);
		break;
	case 9:
		HAL_GPIO_WritePin(SECOND_1_D_GPIO_Port, SECOND_1_D_Pin, GPIO_PIN_SET);
		HAL_GPIO_WritePin(SECOND_1_C_GPIO_Port, SECOND_1_C_Pin, GPIO_PIN_RESET);
		HAL_GPIO_WritePin(SECOND_1_B_GPIO_Port, SECOND_1_B_Pin, GPIO_PIN_RESET);
		HAL_GPIO_WritePin(SECOND_1_A_GPIO_Port, SECOND_1_A_Pin, GPIO_PIN_SET);
		break;
	default:
		break;
	}
}
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
int main(void) {
	/* MCU Configuration--------------------------------------------------------*/

	/* Reset of all peripherals, Initializes the Flash interface and the Systick. */
	HAL_Init();

	/* Configure the system clock */
	SystemClock_Config();

	/* Initialize all configured peripherals */
	MX_GPIO_Init();
	MX_USART2_UART_Init();
	MX_I2C1_Init();
	MX_USART1_UART_Init();
	/* USER CODE BEGIN 2 */
	NEO6_Init(&GpsState, &huart1);
	DS3231_Init(&rtc, &hi2c1);
	uint32_t Timer = HAL_GetTick();
	uint8_t update = 0;
	BuzzerActivate(40);

	/* USER CODE END 2 */

	/* Infinite loop */
	/* USER CODE BEGIN WHILE */
	while (1) {
		/* USER CODE END WHILE */

		/* USER CODE BEGIN 3 */
		if (update == 0) {
			NEO6_Task(&GpsState);
		}

		if ((HAL_GetTick() - Timer) > 100) {

			if (GpsState.Year != 00) {
				if (update == 0) {

					rtc_setup.hour = GpsState.Hour;
					rtc_setup.minute = GpsState.Minute;
					rtc_setup.second = GpsState.Second;
					rtc_setup.day = GpsState.Day;
					rtc_setup.month = GpsState.Month;
					rtc_setup.year = GpsState.Year + 2000;
					DS3231_SetDateTime(&rtc_setup);
					BuzzerActivate(200);
				}
				update = 1;

			}
			if (configMode != 2) {
				DS3231_GetDateTime(&rtc);
				DisplayHour(rtc.hour + timeOffset);
				DisplayMinute(rtc.minute);
				DisplaySecond(rtc.second);

				if (alarmHour == rtc.hour + timeOffset
						&& alarmMinute == rtc.minute && alarmDeactivate == 0) {
					BuzzerActivate(300);
					HAL_Delay(100);
					BuzzerActivate(300);
					alarmDeactivate = 1;
				}

			}
			if(configMode==3)
			{
				displayData();
			}			
			Timer = HAL_GetTick();
		}

	}
	/* USER CODE END 3 */
}

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
/* USER CODE BEGIN 4 */
void HAL_UART_RxCpltCallback(UART_HandleTypeDef *huart) {
	if (huart == GpsState.neo6_huart) {
		NEO6_ReceiveUartChar(&GpsState);
	}
}

void HAL_GPIO_EXTI_Callback(uint16_t GPIO_PIN) {

	if (GPIO_PIN == BUTTON_1_Pin) {
		if (muttexButton1 == 0) {
			if (configMode == 1) {
				configMode = 0;
			} else if (configMode == 2) {
				alarmHour = alarmHour + 1;
				DisplayHour(alarmHour);
				if (alarmHour >= 24) {
					alarmHour = 0;
				}
			} else {
				configMode = 1;
			}
			muttexButton1 = 1;
		}

	}

	if (GPIO_PIN == BUTTON_2_Pin) {
		if (muttexButton2 == 0) {
			if (configMode == 1) {
				timeOffset = timeOffset + 1;
			} else if (configMode == 2) {
				configMode = 0;
			} else {
				configMode = 2;
				alarmDeactivate = 0;
				DisplayHour(0);
				DisplayMinute(0);
				DisplaySecond(0);
			}

			muttexButton2 = 1;
		}
	}
	if (GPIO_PIN == BUTTON_3_Pin) {
		if (muttexButton3 == 0) {
			if (configMode == 1) {
				timeOffset = timeOffset - 1;
			} else if (configMode == 2) {
				alarmMinute = alarmMinute + 1;
				DisplayMinute(alarmMinute);
				if (alarmMinute >= 60) {
					alarmMinute = 0;
				}
			}
			else
			{
				if(configMode==3)
				{
					configMode=0;
				}
				else
				{
					configMode=3;
				}

			}
			muttexButton3 = 1;
		}
	}

	muttexButton1 = 0;
	muttexButton2 = 0;
	muttexButton3 = 0;
}
/* USER CODE END 4 */
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


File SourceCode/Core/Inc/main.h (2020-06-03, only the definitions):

#define B1_Pin GPIO_PIN_13
#define B1_GPIO_Port GPIOC
#define B1_EXTI_IRQn EXTI15_10_IRQn
#define HOUR_1_D_Pin GPIO_PIN_0
#define HOUR_1_D_GPIO_Port GPIOC
#define HOUR_1_C_Pin GPIO_PIN_1
#define HOUR_1_C_GPIO_Port GPIOC
#define HOUR_1_A_Pin GPIO_PIN_2
#define HOUR_1_A_GPIO_Port GPIOC
#define HOUR_1_B_Pin GPIO_PIN_3
#define HOUR_1_B_GPIO_Port GPIOC
#define USART_TX_Pin GPIO_PIN_2
#define USART_TX_GPIO_Port GPIOA
#define USART_RX_Pin GPIO_PIN_3
#define USART_RX_GPIO_Port GPIOA
#define LD2_Pin GPIO_PIN_5
#define LD2_GPIO_Port GPIOA
#define SECOND_2_D_Pin GPIO_PIN_6
#define SECOND_2_D_GPIO_Port GPIOA
#define SECOND_1_D_Pin GPIO_PIN_7
#define SECOND_1_D_GPIO_Port GPIOA
#define MINUTE_1_A_Pin GPIO_PIN_4
#define MINUTE_1_A_GPIO_Port GPIOC
#define BUTTON_2_Pin GPIO_PIN_5
#define BUTTON_2_GPIO_Port GPIOC
#define BUTTON_2_EXTI_IRQn EXTI9_5_IRQn
#define MINUTE_2_D_Pin GPIO_PIN_1
#define MINUTE_2_D_GPIO_Port GPIOB
#define SECOND_2_A_Pin GPIO_PIN_2
#define SECOND_2_A_GPIO_Port GPIOB
#define MINUTE_2_C_Pin GPIO_PIN_10
#define MINUTE_2_C_GPIO_Port GPIOB
#define SECOND_2_B_Pin GPIO_PIN_12
#define SECOND_2_B_GPIO_Port GPIOB
#define MINUTE_1_B_Pin GPIO_PIN_13
#define MINUTE_1_B_GPIO_Port GPIOB
#define MINUTE_1_D_Pin GPIO_PIN_14
#define MINUTE_1_D_GPIO_Port GPIOB
#define MINUTE_2_B_Pin GPIO_PIN_15
#define MINUTE_2_B_GPIO_Port GPIOB
#define BUTTON_1_Pin GPIO_PIN_6
#define BUTTON_1_GPIO_Port GPIOC
#define BUTTON_1_EXTI_IRQn EXTI9_5_IRQn
#define SECOND_1_B_Pin GPIO_PIN_7
#define SECOND_1_B_GPIO_Port GPIOC
#define BUZZER_Pin GPIO_PIN_8
#define BUZZER_GPIO_Port GPIOC
#define SECOND_1_A_Pin GPIO_PIN_8
#define SECOND_1_A_GPIO_Port GPIOA
#define SECOND_2_C_Pin GPIO_PIN_11
#define SECOND_2_C_GPIO_Port GPIOA
#define BUTTON_3_Pin GPIO_PIN_12
#define BUTTON_3_GPIO_Port GPIOA
#define BUTTON_3_EXTI_IRQn EXTI15_10_IRQn
#define TMS_Pin GPIO_PIN_13
#define TMS_GPIO_Port GPIOA
#define TCK_Pin GPIO_PIN_14
#define TCK_GPIO_Port GPIOA
#define HOUR_2_A_Pin GPIO_PIN_15
#define HOUR_2_A_GPIO_Port GPIOA
#define HOUR_2_C_Pin GPIO_PIN_11
#define HOUR_2_C_GPIO_Port GPIOC
#define HOUR_2_B_Pin GPIO_PIN_12
#define HOUR_2_B_GPIO_Port GPIOC
#define HOUR_2_D_Pin GPIO_PIN_2
#define HOUR_2_D_GPIO_Port GPIOD
#define MINUTE_2_A_Pin GPIO_PIN_4
#define MINUTE_2_A_GPIO_Port GPIOB
#define MINUTE_1_C_Pin GPIO_PIN_5
#define MINUTE_1_C_GPIO_Port GPIOB
#define SECOND_1_C_Pin GPIO_PIN_6
#define SECOND_1_C_GPIO_Port GPIOB

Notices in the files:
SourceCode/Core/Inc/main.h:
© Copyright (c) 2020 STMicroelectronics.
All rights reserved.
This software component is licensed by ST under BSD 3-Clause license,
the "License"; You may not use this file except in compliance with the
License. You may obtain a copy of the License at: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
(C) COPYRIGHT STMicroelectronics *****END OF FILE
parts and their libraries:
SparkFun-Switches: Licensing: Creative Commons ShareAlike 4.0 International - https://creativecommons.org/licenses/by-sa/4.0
